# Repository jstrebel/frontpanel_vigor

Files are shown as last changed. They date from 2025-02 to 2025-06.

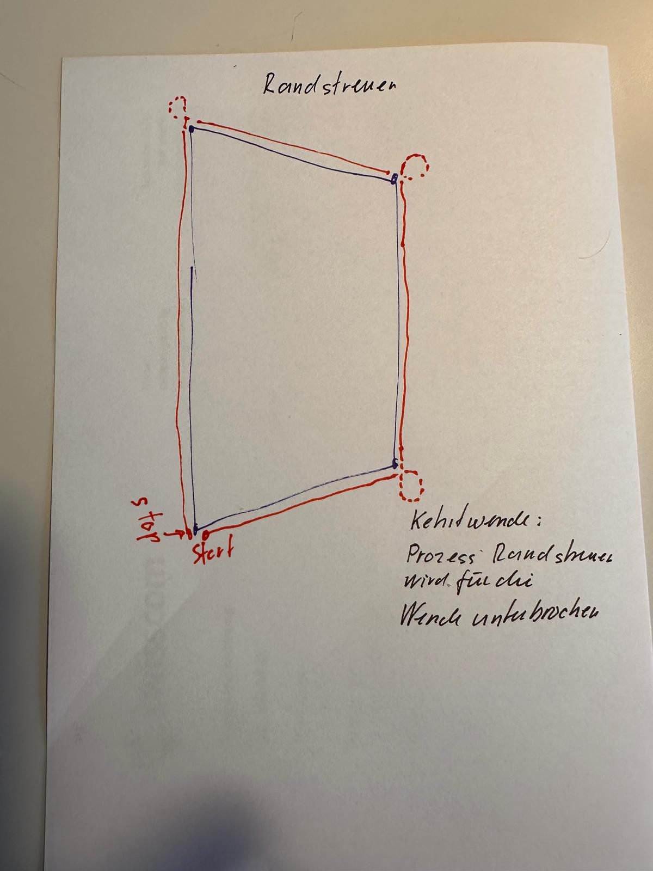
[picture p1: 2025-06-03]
Bedienung/Randstreuen_skizze.jpg

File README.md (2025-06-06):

# vigor frontpanel mit Folientastatur.

Bedienung:  Entwurf der das Bedieninterface der Kotrollerbox erklärt

Schemas:

Testcode:     Beispiel lesen der Tastatur input mit dem Arduino

TFT display:  Für die Anzeigen wird ein gut Dokumentierte Library verwendet.
Doku auf: https://github.com/gavinlyonsrepo/Display_Lib_RPI

Das ist der Code welcher der Entwickler für mich machte.
Dieser Code ist mit dem Raspi 4 getestet.
https://github.com/gavinlyonsrepo/ST7789_TFT_RPI/releases

Gavin hat die Beschreibung upgedatet, Grund war, dass der code den wir verwenden eine andere Library verwendet.
https://github.com/gavinlyonsrepo/ST7789_TFT_RPI

<<<<<<< Updated upstream
<<<<<<< Updated upstream
BEM: werde dieses Repository weiter organisieren und aufräumen 

## Installationen im Raspi

### bcm2835
```
curl -sL http://www.airspayce.com/mikem/bcm2835/bcm2835-1.75.tar.gz | tar xz
./configure
make
sudo make check
sudo make install
```

### redis 
https://fleetstack.io/blog/redis-on-raspberry-pi-setup
```
sudo apt install redis-server -y
```

Falls wenig RAM Memorybegrenzung:
```
sudo nano /etc/redis/redis.conf
maxmemory 100mb maxmemory-policy allkeys-lru
```

Hinzufügen zum Autostart und starten von redis 
```
sudo systemctl  enable  redis-server
sudo systemctl start redis-server
```

Testen:
```
redis-cli
set  testkey  "hello"
get testkey
```

### hiredis
```
sudo apt-get install libhiredis-dev
```
=======
BEM: Werde dieses Repository weiter organisieren und aufräumen
>>>>>>> Stashed changes
=======
BEM: Werde dieses Repository weiter organisieren und aufräumen
>>>>>>> Stashed changes

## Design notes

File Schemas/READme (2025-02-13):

Verkabelung howag: Schemas nach denen Howag die Verkabelung herstellt
Display Anschluss: PCB Verbindungen Display, Folientasten und LED Anzeigen in der Folientastatur
Blockschaltbild: Vigor Bedienung und Regler
Steuerbox: Raspi, und Arduino Display Kontroller
Motor Regler: Steuerung der Linak Linarmotoren. Kommuniziert via CAN Bus mit der Steuerbox

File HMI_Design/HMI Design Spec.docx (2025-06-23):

# HMI Design Spezifikation

# 1 Übersicht

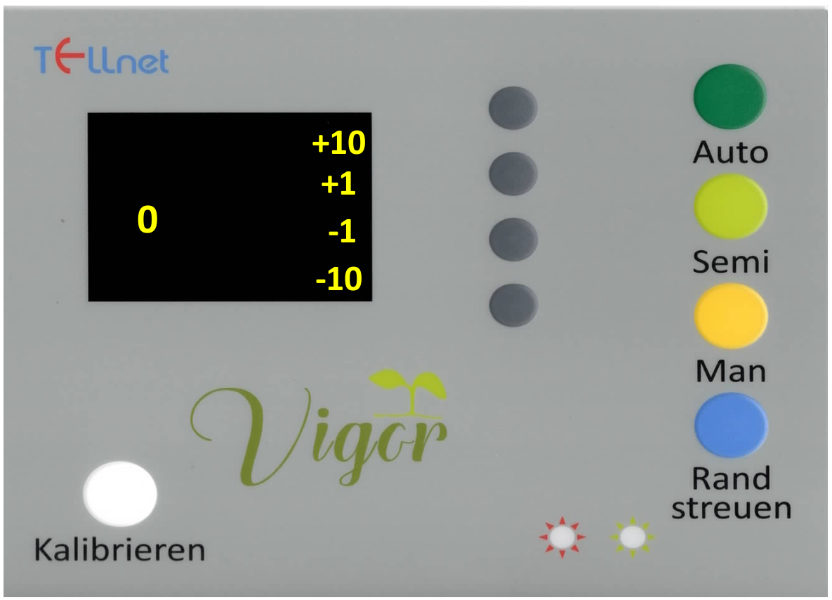
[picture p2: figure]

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
L1 - L7 LEDs

B1 – B5 Knöpfe die mit 3 s debounced werden

B6 – B9 Knöpfe die mit 1 s debounced werden

# 2 Statemachine

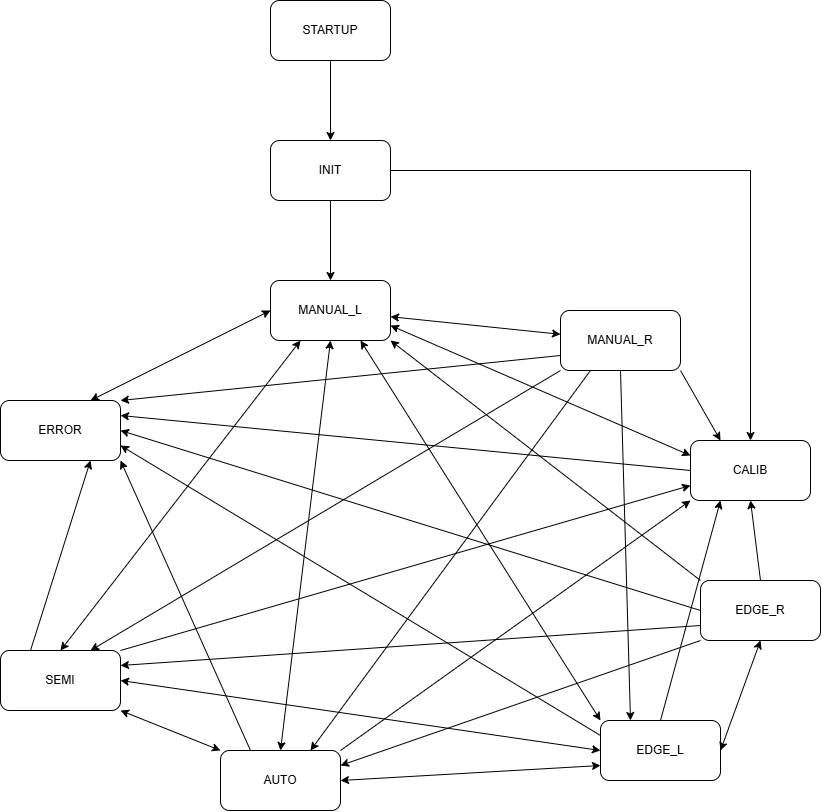
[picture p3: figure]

Alle Verbindungen zum ERROR-State sind im nachfolgenden Kapitel nicht mehr aufgeführt und können durch jeden Fehler zu jedem Zustand hervorgerufen werden.

Der Übergang von STARTUP nach INIT erfolgt nach 10 s.

# 3 UI Konzept

Platzhalter | Bezeichnung | Range | Redis Variable
123 | kalibrierte Position virtueller Anschlag | 0-1023 | hmi_vend_ist
111 | Sollposition virtueller Anschlag | 0-1023 | hmi_vend_soll
11% | Istposition Motor links | 0-100% | hmi_pos_l
22% | Istposition Motor rechts | 0-100% | hmi_pos_r
33% | Sollposition Motor links | 0-100% | hmi_soll_l
44% | Sollposition Motor rechts | 0-100% | hmi_soll_r
Feldname | Name des geladenen Feldes | ?? | hmi_feldname
25 km/h | aktuelle Geschwindigkeit | ?? | hmi_speed
GPS: ok | Status des GPS | ?? | hmi_gps
- | State | - | hmi_state
- | Fehler | 0x01-0x99 | hmi_fehler

Alle Variablen sind vom Datentyp String.

## STARTUP

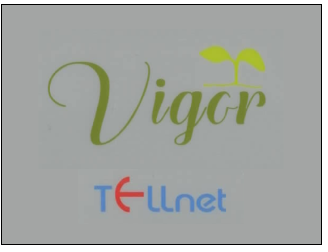
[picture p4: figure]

| Knopf Funktion B1 - B2 - B3 - B4 - B5 - B6 - B7 - B8 - B9 -

## INIT

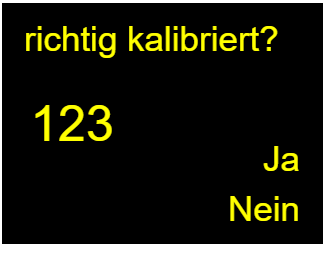
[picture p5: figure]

| Knopf Funktion B1 - B2 - B3 - B4 - B5 - B6 - B7 - B8 - MANUAL_L B9 - CALIB

## CALIB

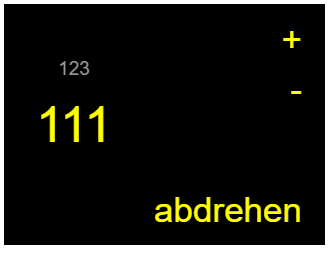
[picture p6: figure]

| Knopf Funktion B1 - AUTO B2 - SEMI B3 - MANUAL_L B4 - EDGE_L B5 vend_prov speichern - MANUAL_L B6 inkrementieren vend_prov B7 dekrementieren vend_prov B8 - B9 Motor links auf vend_prov fahren

## MANUAL_L

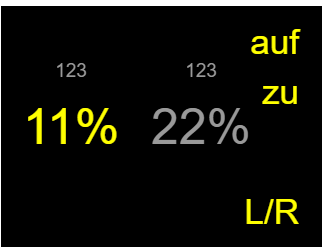
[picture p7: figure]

| Knopf Funktion B1 - AUTO B2 - SEMI B3 - B4 - EDGE_L B5 - CALIB B6 Motor links öffnen B7 Motor links schliessen B8 - B9 - MANUAL_R

## MANUAL_R

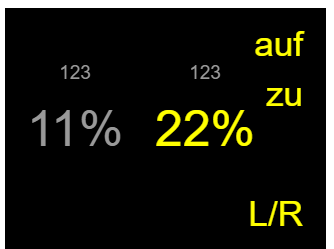
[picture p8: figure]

| Knopf Funktion B1 - AUTO B2 - SEMI B3 - B4 - EDGE_L B5 - CALIB B6 Motor rechts öffnen B7 Motor rechts schliessen B8 - B9 - MANUAL_L

## SEMI

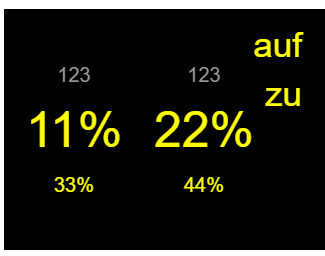
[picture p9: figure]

| Knopf Funktion B1 - AUTO B2 - B3 - MANUAL_L B4 - EDGE_L B5 - CALIB B6 Beide Motoren auf 100% fahren B7 Beide Motoren auf 0% fahren B8 - B9 -

## AUTO

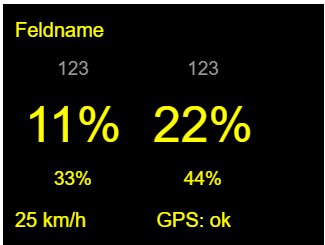
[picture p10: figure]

| Knopf Funktion B1 - B2 - SEMI B3 - MANUAL_L B4 - EDGE_L B5 - CALIB B6 - B7 - B8 - B9 -

## EDGE_L

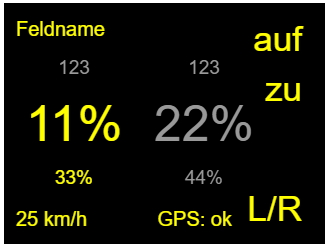
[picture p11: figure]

| Knopf Funktion B1 - AUTO B2 - SEMI B3 - MANUAL_L B4 - B5 - CALIB B6 Motor links auf 100% fahren B7 Motor links auf 0% fahren B8 - B9 - EDGE_R

## EDGE_R

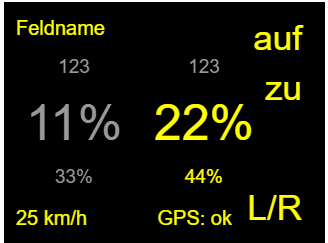
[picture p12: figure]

| Knopf Funktion B1 - AUTO B2 - SEMI B3 - MANUAL_L B4 - B5 - CALIB B6 Motor rechts auf 100% fahren B7 Motor rechts auf 0% fahren B8 - B9 - EDGE_L

## ERROR

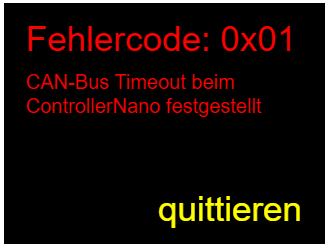
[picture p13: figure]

| Knopf Funktion B1 - B2 - B3 - B4 - B5 - B6 - B7 - B8 - B9 Fehler löschen - MANUAL_L

Fehlercode | Text
0x01 | CAN-Bus Verbindungsunterbruch zum ControllerNano
0x02 | CAN-Bus Verbindungsunterbruch zum Raspberry
0x03 | Motor links einfahren blockiert
0x04 | Motor links ausfahren blockiert
0x05 | Motor rechts einfahren blockiert
0x06 | Motor rechts ausfahren blockiert
0x07 | ??

# 4 Output-Definition

| L1 | L2 | L3 | L4 | L5 | L6 | L7
STARTUP
INIT
CALIB
MANUAL_L
MANUAL_R
SEMI
AUTO
EDGE_L
EDGE_R
ERROR

grün: ON

rot: OFF

blau: BLINK

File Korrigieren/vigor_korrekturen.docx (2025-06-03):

hoi köbi

update zum vigor:

• de widerstand isch de glich gsi wie bim andere multiplexer

• ha jetzt s2 und s1 zemeglötet und jetzt funktionierts

für die nächst Iteration müsst me entweder s2 uf gnd zieh oder am Zero amene freie pin ahenke so dass es nüm Floating irgend es potenzial dra het

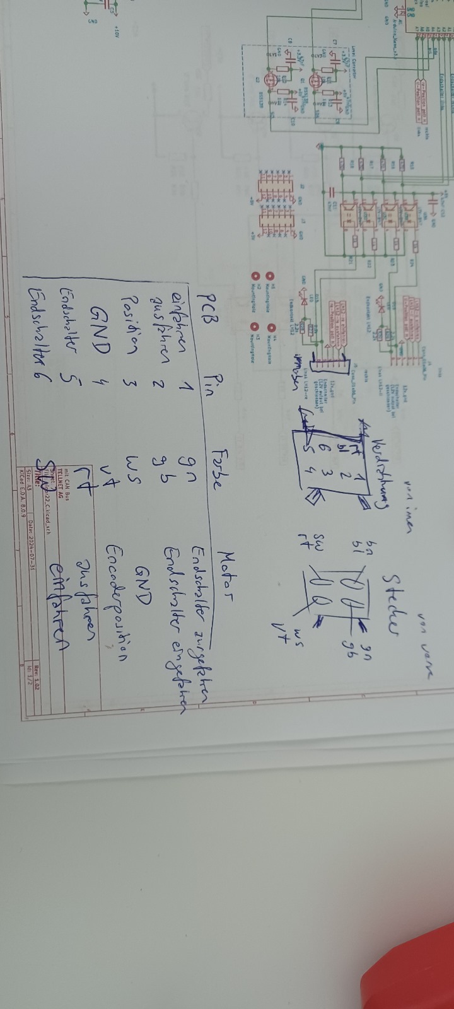
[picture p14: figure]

[13.05.25, 12:42:54] Daniel Jakober: hoi köbi

folgendes Problem:

ich ha ufem raspi d can verbindig wölle teste mitem regler. d verbindig selber het guet funktioniert aber komischerwis hani vom regler immer motorposition 0 übercho was eigentlich gar nit cha si wil de Encoder immer 0.5-4.5v schickt.

denn mol ei Motor abghänkt und wider aghänkt und grad de Arduino gschlisse.

ufgrund vo dem hani denn die neu verkablig dureprüeft und festgstellt dass entweder de motorestecker oder de wissi stecker für ufe print spiegelverchehrt isch. ufem foti gsehsch mini Analyse.

ich probier jetzt mol de Motor manuell z stüre zum luege öb er no funktioniert, wil mit de aktuelle verkablig de Encoder direkt e churze uf gnd gmacht het. falls er no funktioniert luegi öb d platine no lebt, verkable um und nimm e neue Arduino

[13.05.25, 13:38:10] Daniel Jakober: d motore lebe no.

ich nimm ah dass de stecker ufem print bim design oder bim löte verchehrt ume druf cho isch will d howag hets nach ihrem Schema verdrohtet und das passt sowit

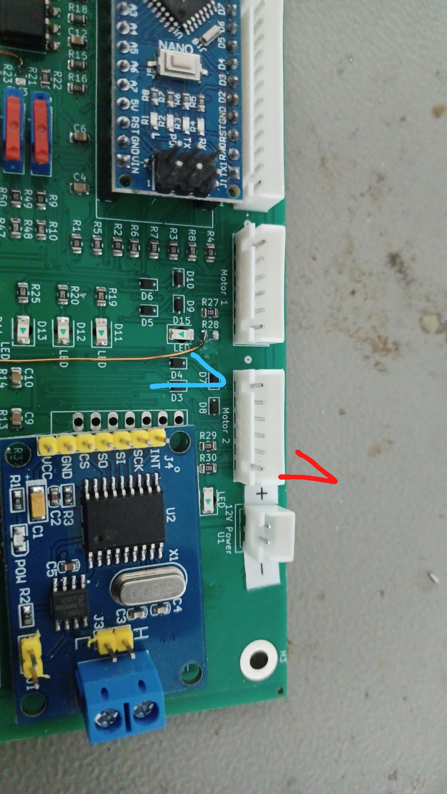
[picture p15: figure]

Rot: stecker pin 1

Blau: platine pin 1

Ich dreih jetz d buchse um denn sötts stimme

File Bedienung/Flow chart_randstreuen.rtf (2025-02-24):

Die Funktion Randstreuen ermöglicht auch eine teilflächenspezifische Düngung, wenn die Feldgrenzen nicht exakt erfasst sind. Dieser Arbeitsschritt steht am Anfang des eigentlichen Düngevorganges. Dabei wird das Feld zu Beginn einmal mit dem Düngerstreuer umfahren. Dabei wird der Dünger nur auf das zu düngende Feld geworfen.
Je nach Strategie oder Düngerstreuer wird das Feld im Uhrzeigersinn (RE) oder Gegen-Uhrzeigersinn (LI) umfahren.

1.Mit dem Traktor zur Anfangsposition fahren.
2.Taste „Man“ 5 Sekunden drücken. → LED „Man“ leuchtet.
3.Taste „Randstreuen“ 5 Sekunden drücken.
1.Anzeige Display Randstreuen
4.Richtung wählen: RE (rechts) oder LI (links).
1.Anzeige Display RE & LI
5.Taste „Randstreuen“ 1 Sekunde drücken.
1.Der Vorgang startet.
2.Sobald der Traktor fährt, öffnet sich der entsprechende Schieber automatisch.
3.LED „Randstreuen“ leuchtet.
6.Ende der Teilstrecke:
1.Traktor kurz anhalten → Schieber schließt automatisch.
2.Taste „Randstreuen“ 1 Sekunde drücken → Unterbrechung zur Wende.
3.LED „Randstreuen“ blinkt.
7.Fortsetzen:
1.Taste „Randstreuen“ erneut 1 Sekunde drücken.
2.LED „Randstreuen“ leuchtet.
3.Sobald der Traktor fährt, öffnet sich der Schieber automatisch.
8.Wiederholen Sie Schritte 5-7, bis das gesamte Feld abgegrenzt ist.
9.Abschluss:
1.Taste „Randstreuen“ 5 Sekunden drücken.

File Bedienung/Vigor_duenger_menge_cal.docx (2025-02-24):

Entwurf: Düngermenge kalibrieren.

Eingabe über Bedienungspanel

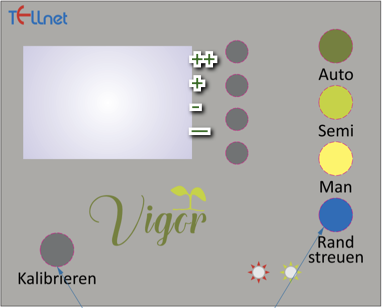
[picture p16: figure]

1) Status setzen Man
2) Button Kalibrieren drücken (5 Sec) (Verriegelung! geht nur wenn Status Man angewählt ist)
3) Kalibriert wird nur mit dem linken Motor. Der rechte Motor (Schieber ist geschlossen)
4) Mit Paneltasten (Funktionstasten neben dem Display) auf grobe Position fahren. (die Position entnimmt der Landwirt einer Tabelle, die vom Düngerstreuer Hersteller geliefert wird)
  a. (wir haben 4 Tasten zur Verfügung. Öffnen/Schliessen, +10, +1, -1, -10)
  b. Anzeige der Position auf dem Display.
    i. 0 -> Linearmotor geschlossen, max. Wert voll ausgefahren.
5) Alternativ: Falls für den gewählten Dünger eine Kalibrierung bereits existiert, wird der Wert mit den Tasten 1-4 eingestellt. Dann gehen Sie direkt zu Punkt 10
6) Abdrehen der Düngemenge (Düngerstreuer wird für eine definierte Zeit eingeschaltet). Die Menge wird danach vom Landwirt mit einer Waage gemessen.
7) Korrigieren (Falls Menge noch nicht OK war)
  a. Wieder wie 3a
  b. Kurzes drücken (0.5 – 1 Sec) von Button Kalibrieren
    i. Motor fährt zuerst etwas Richtung schliessen und danach wieder auf die Position bei der Cal gedrückt wurde. (dies wird gemacht, um das mechanische Spiel zu eliminieren)
8) Erneutes abdrehen (wie punkt 6)
9) If not OK, Wiederholen Step 7
10) IF ok Taste Kalibrieren 5 Sek drücken

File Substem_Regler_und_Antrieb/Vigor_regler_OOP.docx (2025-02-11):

Hier ist die Dokumentation für das angegebene C++-Programm:

## Programmbeschreibung

Dieses C++-Programm steuert ein System, das auf drei Betriebsmodi ausgelegt ist: Semi-Automatik, Automatik und Manuell. Es beinhaltet Fehlerbehandlung, Kommunikationsschnittstellen und LEDs zur Anzeige des Betriebsstatus. Die Hardware wird über I2C und GPIO angesteuert, während verschiedene Zustände und Befehle verarbeitet werden.

## Dateistruktur und Imports

Das Programm verwendet die folgenden benutzerdefinierten Header-Dateien:

- DevOptions.h: Konfigurationseinstellungen.
- PinMap.h: Zuweisung der Hardware-Pins.
- I2C.h: Verwaltung der I2C-Kommunikation.
- Memory.h: Speicherzugriff und Datenpersistenz.
- Logger.h: Protokollierung von Nachrichten.
- LED.h: Steuerung der LEDs.
- CAN.h: (nicht genutzt in diesem Codeabschnitt, möglicherweise für CAN-Kommunikation).
- Controller.h: Steuerung von Motoren.

## Hauptkonstanten und Variablen

### Konstanten

- dt_loop (2 ms): Zeitintervall für die Hauptschleife.

### Globale Variablen

- old_loop_time: Verfolgt die vergangene Zeit zwischen Schleifendurchläufen.
- curr_state: Gibt den aktuellen Betriebsmodus an.
  - 1: Semi-Automatik
  - 2: Automatik
  - 3: Manuell
  - 4: Fehler
- err_shout: Kontrolliert die Fehlerprotokollierung.
- Controller-Objekte: controller_l (links) und controller_r (rechts).
- LED-Objekte: led_red (rot) und led_green (grün).

## Programmfluss

### 1. setup()

Initialisierung der Hardware und der Controller:

1. Initialisierung der Pin-Zuweisung (via PinMap).
2. Initialisierung des Loggers und der I2C-Kommunikation.
3. Erstellung der Controller-Objekte mit ihren zugehörigen Pins und initialen Einstellungen.
4. Initialisierung der LED-Objekte.
5. Protokollierung der Startmeldung.

### 2. loop()

Wird in regelmäßigen Intervallen (dt_loop) ausgeführt und enthält die Hauptlogik:

- I2C-Register-Updates: Synchronisation von Status und Motorpositionen mit den I2C-Registern.
- Moduswechsel: Verarbeitung des aktuellen Modus und Zustandsänderungen basierend auf Eingaben.
- Fehlerbehandlung: Automatische Fehlerkorrektur und Protokollierung.

#### Betriebsmodi

1. Semi-Automatik (State 1):
  - Motorsteuerung basierend auf semiautomatischen Regeln.
  - Aktivierung der grünen LED.
  - Umschaltung in andere Modi basierend auf Schalterstellungen.
2. Automatik (State 2):
  - Motorsteuerung basierend auf Referenzwerten aus dem I2C-Register.
  - Verbindungskontrolle über das Heartbeat-Register.
  - LED-Anzeigen anpassen und Umschaltung in andere Modi.
3. Manuell (State 3):
  - Motorstillstand (Halt).
  - Möglichkeit, virtuelle Endanschläge zu speichern.
  - LED-Anzeigen anpassen und Umschaltung in andere Modi.
4. Fehler (State 4):
  - Motorbewegung zur Fehlerkorrektur (Home).
  - Protokollierung von Fehlern und Aktivierung der roten LED.
  - Fehlerzustand bleibt bestehen, bis er manuell zurückgesetzt wird.

### 3. update_state(short state)

Wechselt den aktuellen Zustand des Systems:

1. Beendet aktuelle Motoraktivitäten.
2. Setzt die I2C-Referenzregister zurück.
3. Protokolliert den Wechsel in den neuen Zustand.

### 4. update_status()

Aktualisiert den Status des Systems und verarbeitet Befehle aus dem I2C-Befehlsregister:

- Speichert neue virtuelle Endanschläge.
- Setzt Fehler zurück.
- Veranlasst einen Übergang aus dem Fehlerzustand.
- Aktualisiert Fehler-Flags und Zustandsbits im Statusregister.

### 5. I2C-Ereignisfunktionen

- receiveEvent(int howMany): Empfängt Daten über I2C.
- requestEvent(): Beantwortet I2C-Anfragen.

## Funktionen der Klassen

1. Controller: Verarbeitet Motorsteuerung (Halt, Semi-Automatik, Automatik, Fehlerkorrektur).
2. LED: Steuert die LEDs (z. B. Blinken, Ein-/Ausschalten).
3. Memory: Speichert und liest die virtuellen Endanschläge.
4. Logger: Protokolliert Ereignisse und Statusänderungen.
5. I2C: Schnittstelle zur Kommunikation und Registerverwaltung.

## Fehlerbehandlung

- Überwacht Watchdog- und Timeout-Fehler.
- Protokolliert spezifische Fehler basierend auf Status-Bits.
- Verhindert wiederholte Fehlermeldungen (err_shout).

## Zusammenfassung

Das Programm ist ein robustes Steuerungssystem, das mehrere Modi unterstützt, eine präzise Motorsteuerung ermöglicht und eine zuverlässige Fehlerbehandlung bietet. Es ist modular aufgebaut, was die Erweiterbarkeit erleichtert.

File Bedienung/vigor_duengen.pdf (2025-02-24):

# Düngen

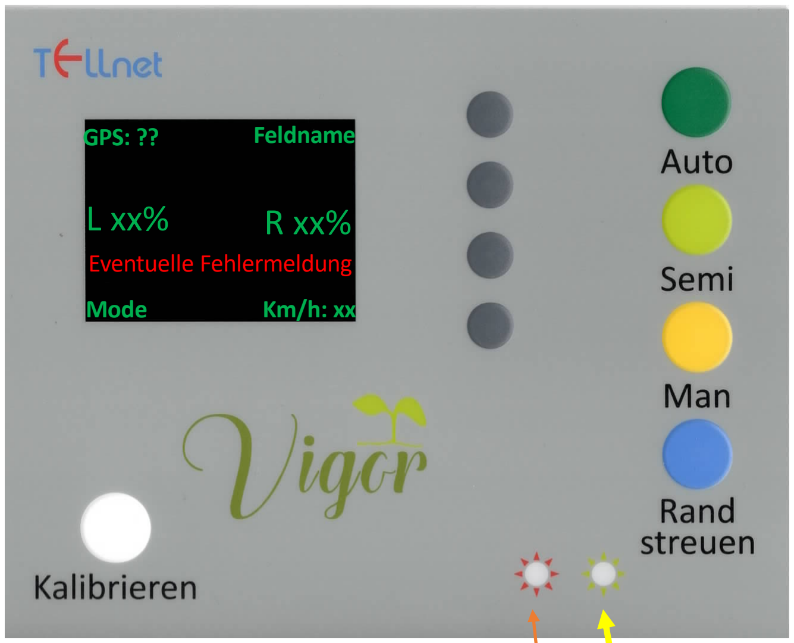
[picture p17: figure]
GPS: ??; Feldname; Mode; Eventuelle Fehlermeldung

### Anzeigen Düngemodus - GPS Status: (locked, not ready) L oder S

- Feldname: Hier wird das Feld angezeigt,

### das in unmittelbarer Nähe ist oder gedüngt

wird.

### - %tuale Schierberöffnung - Betriebsmodus: (Auto, Semi, Man) Kalibrieren, Geschwindigkeit)

## LED ON Alles OK - Kalibrierung ok - Motor Initialisierung ok Bereit zum düngen LED blinkend Bereit zum Düngen, noch kein Düngeplan geladen

## Blinkmuster Müssten noch definiert werden

# Bedienung

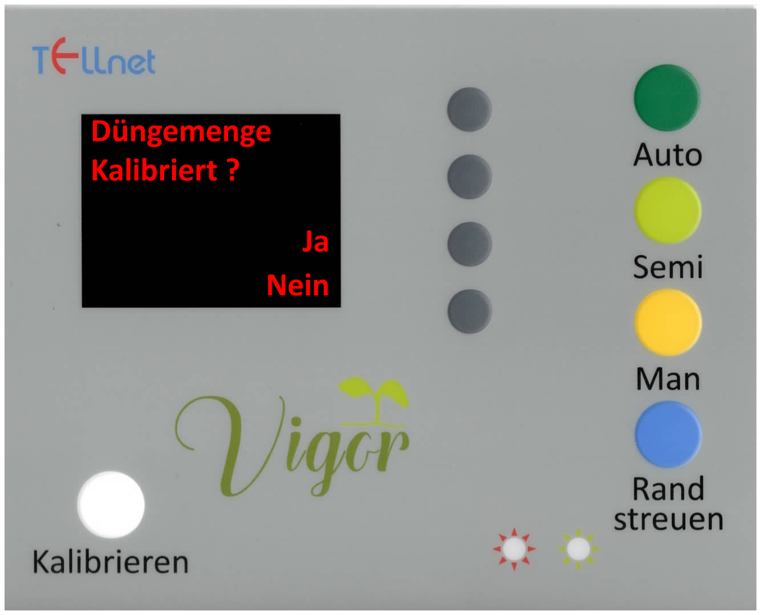
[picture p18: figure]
Düngemenge Kalibriert ?; Nein

Einschalten und Ausgangsposition:
- Schalten Sie den Vigor Düngerstreuer ein.
- Das System startet automatisch im manuellen Modus.
- Die Schieber des Streuers werden initial geschlossen. Kalibrierungsprüfung:
- Auf dem Display erscheint die Frage: "Ist der Düngerstreuer kalibriert?"
- Wählen Sie mit der entsprechenden Taste "Ja" oder "Nein". Kalibrierung (falls erforderlich):
- Wenn "Nein" gewählt wurde:
- Navigieren Sie gemäß den Anweisungen auf dem Display zum Menüpunkt "Düngermenge kalibrieren".
- Führen Sie die Kalibrierung gemäß den detaillierten Anweisungen im Kalibrierungsmenü durch.
Betriebsbereitschaft:
- Wenn "Ja" gewählt wurde oder die Kalibrierung erfolgreich abgeschlossen ist:
- Der Düngerstreuer ist nun betriebsbereit.
- Sie können nun die gewünschten Düngekarten in das System laden.
- Fahren Sie zu den entsprechenden Feldern, um mit dem Düngen zu beginnen.

# Kalibrieren

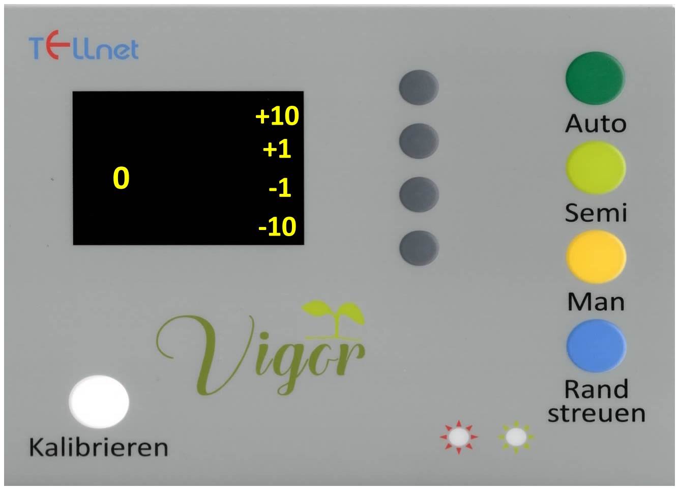
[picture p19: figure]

### 1) Status setzen: Man 2) Button Kalibrieren drücken (5sec) (Verriegelung! geht nur, wenn Status Man angewählt ist) 3) Kalibriert wird nur mit dem linken Motor. Der rechte Motor (Schieber ist geschlossen)

4) Mit Paneltasten (Funktionstasten neben dem Display) auf grobe Position fahren.
(die Position entnimmt der Landwirt einer Tabelle, die vom Düngerstreuer Hersteller geliefert wird)

### a. (wir haben 4 Tasten zur Verfügung. +10, +1, -1, -10)

b. Anzeige der Position auf dem Display.
i. 0 -Schieber geschlossen, max. Wert voll ausgefahren.

5) Alternativ: Falls für den gewählten Dünger eine Kalibrierung bereits existiert, wird der Wert mit den Tasten 1-4 eingestellt. Dann gehen Sie direkt zu Punkt 10 6) Abdrehen der Düngemenge (Düngerstreuer wird für eine definierte Zeit eingeschaltet). Die Menge wird danach vom Landwirt mit einer Waage

gemessen.

7) Korrigieren (Falls Menge noch nicht OK war) a. Wie 3a b. Kurzes drücken (0.5 – 1sec) von Button Kalibrieren i. Motor fährt zuerst etwas Richtung schliessen und danach wieder auf die Position bei der Cal gedrückt wurde. (dies wird gemacht, um das mechanische Spiel zu eliminieren) 8) Erneutes abdrehen (wie Punkt 6) 9) IF not OK, Wiederholen (wie Punt 7) 10) IF ok Taste Kalibrieren 5 Sek drücken

# Randstreuen

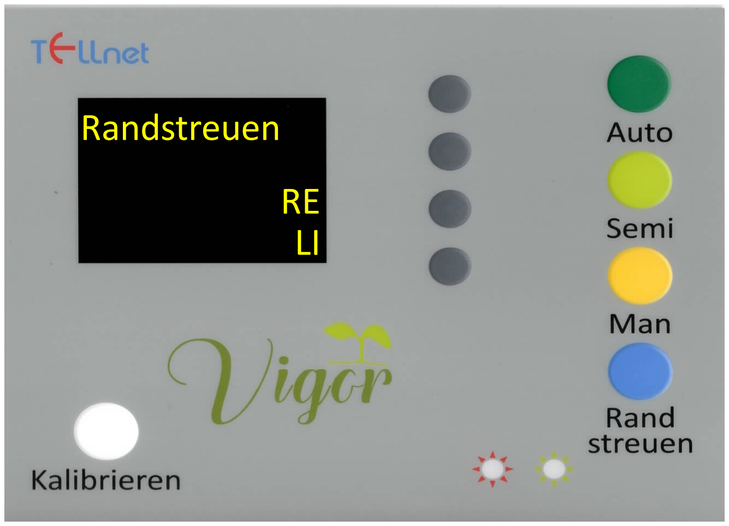
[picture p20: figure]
Randstreuen

Die Funktion Randstreuen ermöglicht auch eine teilflächenspezifische Düngung, wenn die Feldgrenzen nicht exakt erfasst sind. Dieser Arbeitsschritt steht am Anfang des eigentlichen Düngevorganges. Dabei wird das Feld zu Beginn einmal mit dem Düngerstreuer umfahren. Dabei wird der Dünger nur auf das zu düngende Feld geworfen.
Je nach Strategie oder Düngerstreuer wird das Feld im Uhrzeigersinn (RE) oder Gegen-Uhrzeigersinn (LI) umfahren.

1.Mit dem Traktor zur Anfangsposition fahren.
2.Taste „Man“ 5 Sekunden drücken. → LED „Man“ leuchtet. 3.Taste „Randstreuen“ 5 Sekunden drücken.
1.Anzeige Display Randstreuen
4.Richtung wählen: RE (rechts) oder LI (links).
1.Anzeige Display RE & LI
5.Taste „Randstreuen“ 1 Sekunde drücken.
1. Der Vorgang startet.
2. Sobald der Traktor fährt, öffnet sich der entsprechende Schieber automatisch.
3. LED „Randstreuen“ leuchtet.
6.Ende der Teilstrecke:
1. Traktor kurz anhalten → Schieber schließt automatisch.
2. Taste „Randstreuen“ 1 Sekunde drücken → Unterbrechung zur Wende.
3. LED „Randstreuen“ blinkt.
7.Fortsetzen:
1. Taste „Randstreuen“ erneut 1 Sekunde drücken.
2. LED „Randstreuen“ leuchtet.
3. Sobald der Traktor fährt, öffnet sich der Schieber automatisch. 8.Wiederholen Sie Schritte 5-7, bis das gesamte Feld abgegrenzt ist. 9.Abschluss:
1. Taste „Randstreuen“ 5 Sekunden drücken.

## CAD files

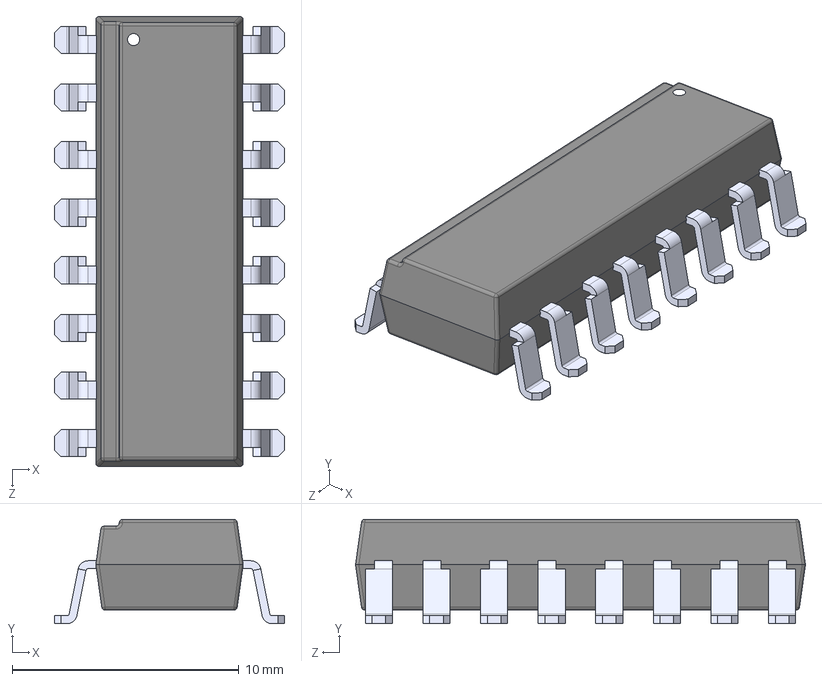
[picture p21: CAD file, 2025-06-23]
KiCAD/vigor22_C/LTV-847S/LTV-847S.step
10.2 x 4.60 x 19.8 mm

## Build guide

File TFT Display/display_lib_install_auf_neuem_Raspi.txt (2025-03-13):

pi@vigor:~ $ curl -sL https://github.com/gavinlyonsrepo/ST7789_TFT_RPI/archive/1.0.2.tar.gz | tar xz

pi@vigor:~ $ ls
Display_Lib_RPI-2.2.0  lg  lg.zip  ST7789_TFT_RPI-1.0.2
pi@vigor:~ $ cd ST7789_TFT_RPI-1.0.2/

********************************

/Display_Lib_RPI-2.2.0
Installieren 

in home von pi
pi@vigor:~ $ ls -l
total 2684
drwxr-xr-x 8 pi pi    4096 Mar 12 09:19 Display_Lib_RPI-2.2.0
drwxr-xr-x 7 pi pi    4096 Mar 12 08:21 lg
-rw-r--r-- 1 pi pi 2739152 May  3  2023 lg.zip

wget http://abyz.me.uk/lg/lg.zip
unzip lg.zip
cd lg
make
sudo make install

macht Fehler
pi@vigor:~/lg $ sudo make install
install -m 0644 lgpio.h                  /usr/local/include
install -m 0644 rgpio.h                  /usr/local/include
install -m 0755 liblgpio.so.1 /usr/local/lib
install -m 0755 librgpio.so.1 /usr/local/lib
install -m 0755 rgpiod                   /usr/local/bin
install -m 0755 rgs                      /usr/local/bin
install -m 0644 rgpiod.1                 /usr/local/man/man1
install -m 0644 rgs.1                    /usr/local/man/man1
install -m 0644 lgpio.3                  /usr/local/man/man3
install -m 0644 rgpio.3                  /usr/local/man/man3
ldconfig
/usr/bin/python3
Traceback (most recent call last):
  File "/home/pi/lg/PY_RGPIO/setup.py", line 3, in <module>
    from setuptools import setup
ModuleNotFoundError: No module named 'setuptools'
*** install of Python3 rgpio.py failed ***
/usr/bin/python3

sudo apt-get install python3-pip

danach	 gehts

cd Display_Lib_RPI-2.2.0
make
sudo make install

cd examples
# Edit the makefile in examples folder by picking the "SRC" file path you want to run

/Display_Lib_RPI-2.2.0/examples $ make help
Makefile:140: *** SRC example file path is not set, pick a SRC path in Section A, exiting nothing done.  Stop.

# =============== ST7789 TFT LCD SPI =============

SRC=st7789/Hello_world

make
make run

 make run
Bin/test.out
TFT Start Test 101 HWSPI
ST7789 library version : 220
Lgpio library version :131584
Hello World
Error: spiWriteDataBuffer: Failure to Write SPI :(spi xfer/read/write failed)
The problem maybe: The spidev buf size setting must be set at 65536 bytes or higher.
See readme, note section, of relevant display at https://github.com/gavinlyonsrepo/Display_Lib_RPI for more details
spidev buf defines the number of bytes that the SPI driver will use as a buffer for data transfers.
Error: spiWriteDataBuffer: Failure to Write SPI :(spi xfer/read/write failed)
The problem maybe: The spidev buf size setting must be set at 65536 bytes or higher.
See readme, note section, of relevant display at https://github.com/gavinlyonsrepo/Display_Lib_RPI for more details
spidev buf defines the number of bytes that the SPI driver will use as a buffer for data transfers.
TFT End

Lösung:

If it is lower than 65536 you can change it by adding this to the start of line in file /boot/firmware/cmdline.txt. Make sure everything is on one line and there is space ' ' between this parameter and next one. Then reboot machine. Verify again by running last cat command above

spidev.bufsiz=65536

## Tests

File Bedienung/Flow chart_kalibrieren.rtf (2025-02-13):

Erstelle Flow Chart mit Gemini:
Funktion kalibrieren:

Funktion F0:
If Cal Button pressed < 1sec
if no valid Value, display: Not Calibrated
display value result.

Funktion F1:
LED cal OFF
Press Cal Button for 5 sec
Blink LED cal
Close Schieber

Funktion F2:
betätige Funktionstasten (+10 / +1/ -1/ -10)
Move Schieber to Position selected by Funktionstasten
Display Position
Motor Position OK ?
Press Cal Button for 1sec

Funktion F3: (Funktion to overcome mechanical hysteresis.
Move Schieber -10%
Move Schieber back to Position when Button cal was pressen.

Funktion F4: External Funktion by User: Check result
IF result not OK go F2
IF result OK
Display Text: Press Cal for 5sec
LED Cal ON

Antwort Gemini:

Explanation:
1 Start: The process begins.
2 Function F0:
◦ Check Cal Button: If the button is pressed for less than 1 second:
▪ Check Valid Value: If a valid value is present, display it.
▪ No Valid Value: If no valid value is present, display "Not Calibrated."
3 Function F1:
◦ LED Cal OFF: Turn off the calibration LED.
◦ Press Cal Button: Wait for the button to be pressed for 5 seconds.
◦ Blink LED Cal: Blink the calibration LED.
◦ Close Schieber: Close the slider.
4 Function F2:
◦ Press Function Buttons: Press the desired function button (+10, +1, -1, -10).
◦ Move Schieber: Move the slider to the position selected by the function buttons.
◦ Display Position: Display the current position.
◦ Check Motor Position: Verify if the motor is in the correct position.
▪ Yes: Proceed to Function F3.
▪ No: Go back to Function F2.
5 Function F3:
◦ Move Schieber -10%: Move the slider 10% backward.
◦ Move Schieber Back: Move the slider back to the position when the calibration button was pressed.
6 Function F4:
◦ External Check: Perform an external check of the result.
▪ Result Not OK: Go back to Function F2.
▪ Result OK: Display "Press Cal for 5sec" and turn on the calibration LED.
7 End: The process ends.

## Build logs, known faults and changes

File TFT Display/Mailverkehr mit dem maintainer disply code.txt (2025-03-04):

MAIL Verkehr mit dem Maintainer des Display Codes:
(chronlogie: Neueste am Anfang)

Hi Gavin,
I intend to use the ST7789_TFT_RPI lib. The lib you did for me.
Is there a possibility to merge this into 2.0. Or should I stay with 1.3?
Regards
Jakob

Am 23.12.2024 um 20:04 schrieb Gavin Lyons <glyons66@hotmail.com>:

Hi 

You are using Display_Lib_RPI not ST7789_TFT_RPI
ST7789_TFT_RPI is  the library I wrote for you.

The problem is:  that I upgraded 'Display_Lib_Rpi' from version 1.3.0 to Version 2.0.0. Last month.
So it will work on all Linux based Single board computers Including  Raspberry pi 5.  
'Display_Lib_Rpi'  version 2.0.0 may require a change to the 'spidev.bufsiz' setting  as specified in the st7789 readme.

Do you want to use Display_lib_RPI OR St7789_TFT_RPI ?
St7789_TFT_RPi is unchanged since last contact and should work fine.

Regards 
Am 23.11.2024 um 14:57 schrieb Gavin Lyons <glyons66@hotmail.com>:

Hi 

I have created a new version: 1.0.2 , which has support for hardware SPI-1 interface.
There are 3 hello world examples (one for SPI-0 , SPI-1 and software SPI)
The only difference is in setup*() function.
 The difference between SPI-0 and SPI-1 is the number of parameters for TFTInitSPI() function.
For SPI-1 there is no choice for CE pin.
I have noticed the speed of SPI-1 is ~50% of SPI-0, I don't know reason why , its not my library, its the bcm2835 library or
Raspberry pi configuration.
Pins used are in README table. 
I never used the SPI-1 before on any project.
Regards
From: Jakob Strebel <jkstrebel@gmail.com>
Sent: Friday 22 November 2024 18:22
To: Gavin Lyons <glyons66@hotmail.com>
Subject: Re: Display Lib st7789 change to Landscape?

Good evening Gavin,

Thank you for the response. Because i am only displaying Text, I guess Software SPI could do the job, right?
The Library as it is has NO option to use  SPI1 
It needs to be changed to use 'bcm2835_aux_spi_*'  functions instead of the  'bcm2835_spi_*'  from bcm2835 dependency library.
I have never used  'bcm2835_aux_spi_*' before but assuming it works it should be an easy job. 
The library does support  software SPI , but this is 20 times slower than 8MhZ Hardware SPI, the advantage of software SPI is you can 
Pick any GPIO you want. 
I can add an option to use SPI1 OR show you how to do software SPI(its shown in hello world example , function = SetupSWSPI()) 

This would be very helpful. 
Regards Jakob

regards
   

From: Jakob Strebel <jkstrebel@gmail.com>
Sent: Thursday 21 November 2024 16:49
To: Gavin Lyons <glyons66@hotmail.com>
Subject: Re: Display Lib st7789 change to Landscape?
 
Gavin,
I hope you got the money. With Paypal the conversion from Swiss Francs, went to US$ and then to EU. This ist the reason for the odd value.

As I confimed yesterday, all works. Thank you.

Right now I am struggling because I need to move the display from the SPI 0 channel to SPI 1.
I could you give me please give me a hint?
Below the Actual pin Config which works. 
Where do I make the all the changes to use SPI 1?

Thank you Jakob

<PastedGraphic-1.png>

Am 20.11.2024 um 17:15 schrieb Gavin Lyons <glyons66@hotmail.com>:

Hi 

I have made a new library at https://github.com/gavinlyonsrepo/ST7789_TFT_RPI
You can test it and see how it works.
I think it will work for 240x320 but i am not certain.

Regards

From: Jakob Strebel <jkstrebel@gmail.com>
Sent: Tuesday 19 November 2024 16:37
To: Gavin Lyons <glyons66@hotmail.com>
Subject: Re: Display Lib st7789 change to Landscape?
 
Hi Gavin,
thank you for the quick response.

So you want a ST7789 Library for Raspberry pi 3 or 4 written in C++, 240x320 Landscape mode.
Yes

Note ::
I have a 240X280 display but the same code should work for 240x320.

Lets give a try with this version. I guess to change it to 240x320 should not be a ig issue.

The 'Display_Lib_RPI' library  does not work at present  with Raspberry pi 5 as the bcm2835 Library dependency its built on is not updated to work  on Raspberry pi 5.

I am aware of this. I am using RP4 ad CM4 with bookworm. Never seen any problem between the two platforms.
Regards Jakob

regards
 
From: Jakob Strebel <jkstrebel@gmail.com>
Sent: Tuesday 19 November 2024 09:30
To: Gavin Lyons <glyons66@hotmail.com>
Subject: Re: Display Lib st7789 change to Landscape?
 
Gavin,
thank you for the response. The positive result lead me to ask you for some work.  I am able to pay a small amount for it.

I am planning to build a small series of devices that will help farmers to reduce the need for fertilizer in order to conserve drinking water. Our aim is to provide around 20-30 farmers with a low-cost device next spring.
We use a TFT display to show the operating status. 
240x320 in landscape mode.
I have discovered your Display_Lib_RPI library.
could you please adapt this library for the ST7789v to:
240x320 Landscape mode. Would this be possible for 100€
Our project is also open source https://github.com/jaluebbe/vigor22

Regards Jakob

Am 17.11.2024 um 23:16 schrieb Gavin Lyons <glyons66@hotmail.com>:

Hi 

You can use command  TFTsetRotation(); to rotate the display.
https://gavinlyonsrepo.github.io/misc/software_docs/Display_Lib_RPI/classST7789__TFT.html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

See test 502 in example file Text_Graphics_Functions/main.cpp 
you have to edit the examples/color16_displays/Makefile To SRC=st7789/Text_Graphics_Functions to run this test file. As per main README test section.

regards.

From: Jakob Strebel <jkstrebel@gmail.com>
Sent: Sunday 17 November 2024 13:39
To: glyons66@hotmail.com <glyons66@hotmail.com>
Subject: Display Lib st7789 change to Landscape?
 
Gavin, great to see what you have done. Thank you for the good description. It helped me to make it run for a st7788 to display Text.

I was searching in the code to find any hints how to change the text display from portrait to landscape mode.
Could you please give me hints wherei can do this?

Regards Jakob

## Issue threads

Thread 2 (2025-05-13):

Adresspin Ti2-S2 fehlt

danielfhnw, 2025-05-13:
Beim Multiplexer U6 für den K9 fehlt der Anschluss am S2.

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

Könnte entweder direkt auf GND gezogen , aber dadurch verlieren wir 4 Kanäle oder am Raspi Zero an einem freien Pin angehängt werden.

danielfhnw, 2025-05-13:
Aktueller Hotfix: S1 und S2 zusammengelötet.

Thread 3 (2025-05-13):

Spiegelverkehrte Stecker

danielfhnw, 2025-05-13:
Der Motorenstecker und die Verkabelung von Howag passen nicht mit der Pinbelegung auf dem Schema überein. Entweder ist der Motorenstecker oder der weisse Stecker für auf den Print spiegelverkehrt verkabelt.

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

danielfhnw, 2025-05-13:
Hotfix: beide PCB-Buchsen gedreht.
Anhand des Footprints sind sie wahrscheinlich 180° verdreht im KiCad

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

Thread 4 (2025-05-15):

FPC spiegelverkehrt

danielfhnw, 2025-05-15:
Der SMD-Flachbandconnector stimmt in der angedachten Ausrichtung nicht mit der Nummerierung des Kabels überein.

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

danielfhnw, 2025-05-15:
Hotfix: Kabel um 180° gedreht damit die Pins übereinstimmen. Kann aber auf Dauer nicht funktionieren, da das Kabel stark verbogen ist.

danielfhnw, 2025-05-15:
Update: Kabel kaputt

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

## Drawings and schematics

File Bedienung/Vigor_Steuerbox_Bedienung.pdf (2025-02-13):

# Vigor Blockschaltbild

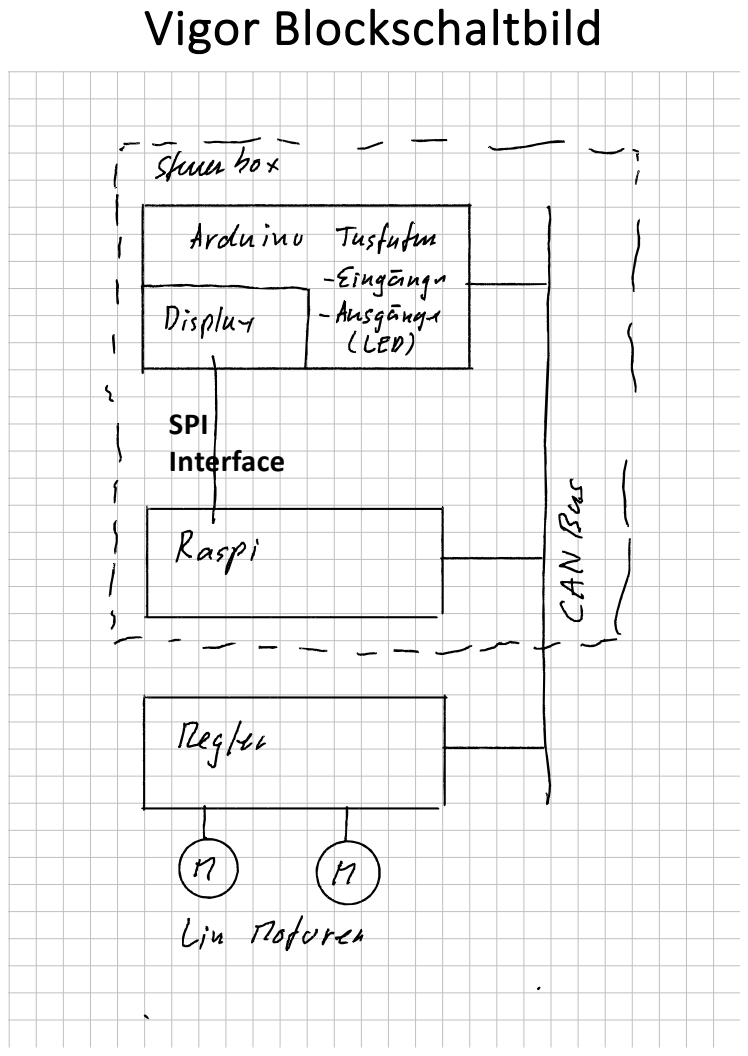
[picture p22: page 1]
SPI Interface

## Anzeige: Betriebsmodus (düngen)

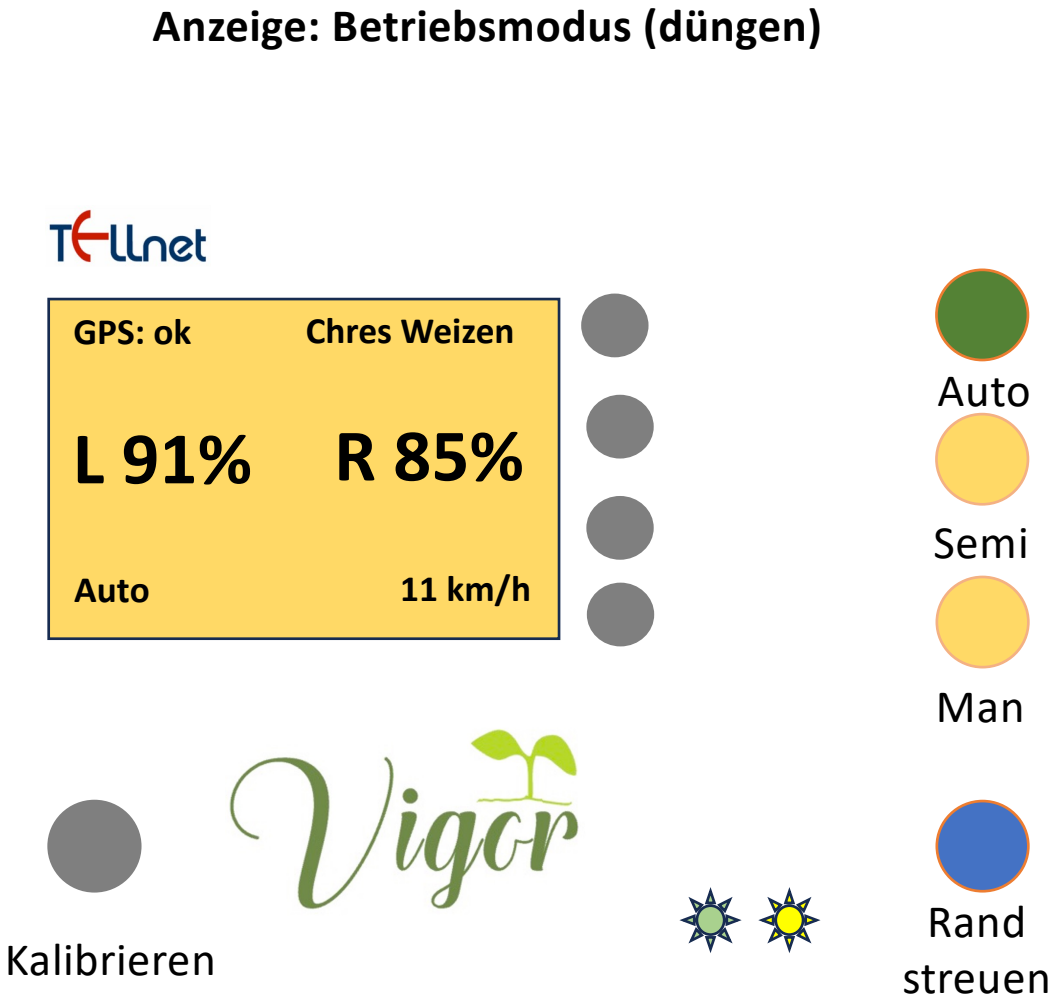
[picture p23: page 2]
Rand streuen Kalibrieren; Man; Semi; Auto; GPS: ok; Chres Weizen

## Erklärungen: Anzeigen

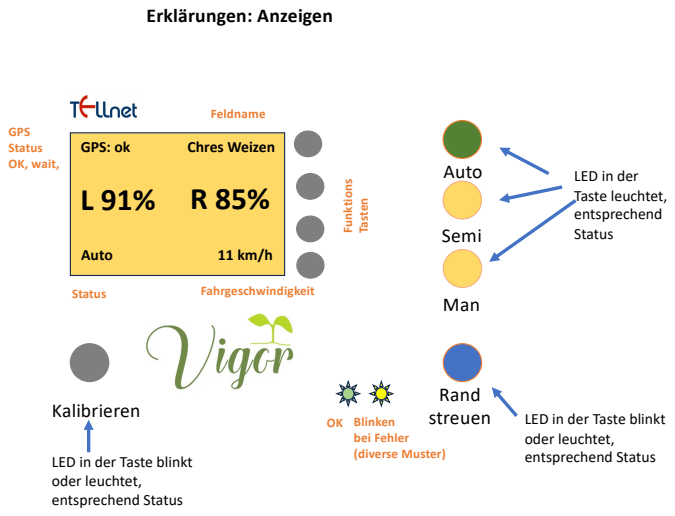
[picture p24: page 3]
Rand streuen Kalibrieren; Man; Semi; Auto; GPS: ok; Chres Weizen; Feldname; Funktions Tasten; Fahrgeschwindigkeit Status; OK Blinken bei Fehler (diverse Muster); GPS Status OK, wait,

LED in der
Taste leuchtet,
entsprechend
Status

LED in der Taste blinkt
oder leuchtet,
entsprechend Status

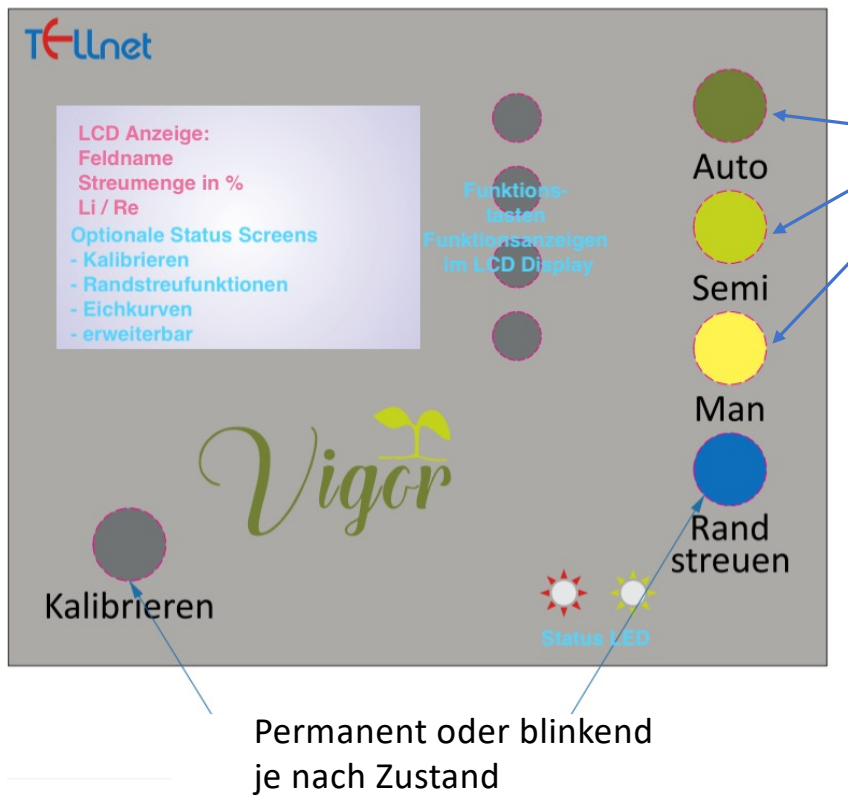
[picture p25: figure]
Permanent oder blinkend je nach Zustand

In den Tasten
ist eine LED die
permanent leuchtet

## Erklärungen zu LCD Anzeige

# Kalibrieren

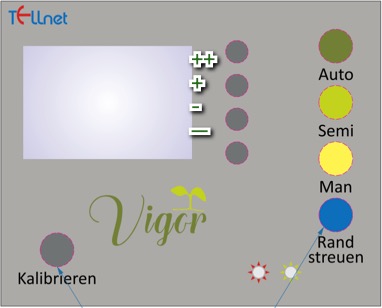
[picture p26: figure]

1) Status setzen: Man
2) Button Kalibrieren drücken (5sec) (Verriegelung! geht nur, wenn Status Man angewählt ist)
3) Mit Paneltasten (Funktionstasten neben dem Display) auf grobe Position fahren. (die Position entnimmt der Landwirt einer Tabelle)
a. (wir haben 4 Tasten zur Verfügung. Öffnen/Schliessen, grosse Schritte kleine Schritte)
b. Anzeige der Position auf dem Display.
i. 0 -> voll Button geschlossen, max. Wert voll ausgefahren.
4) Abdrehen der Menge (Düngerstreuer wird für eine definierte Zeit betätigt. Die Menge wird danach vom Landwirt mit einer Waage gemessen.
5) Korrigieren (Falls Menge noch nicht OK war
a. Wie 3a
b. Kurzes drücken (0.5 - 1sec) von Button Kalibrieren
i. Motor fährt zuerst etwas Richtung schliessen und danach wieder auf die Position bei der Cal gedrückt wurde. (dies wird gemacht, um das mechanische Spiel zu eliminieren)
6) Erneutes abdrehen (wie Punkt 4)
7) IF not OK, Wiederholen Step 5
8) IF ok Taste Kalibrieren 5 Sek drücken

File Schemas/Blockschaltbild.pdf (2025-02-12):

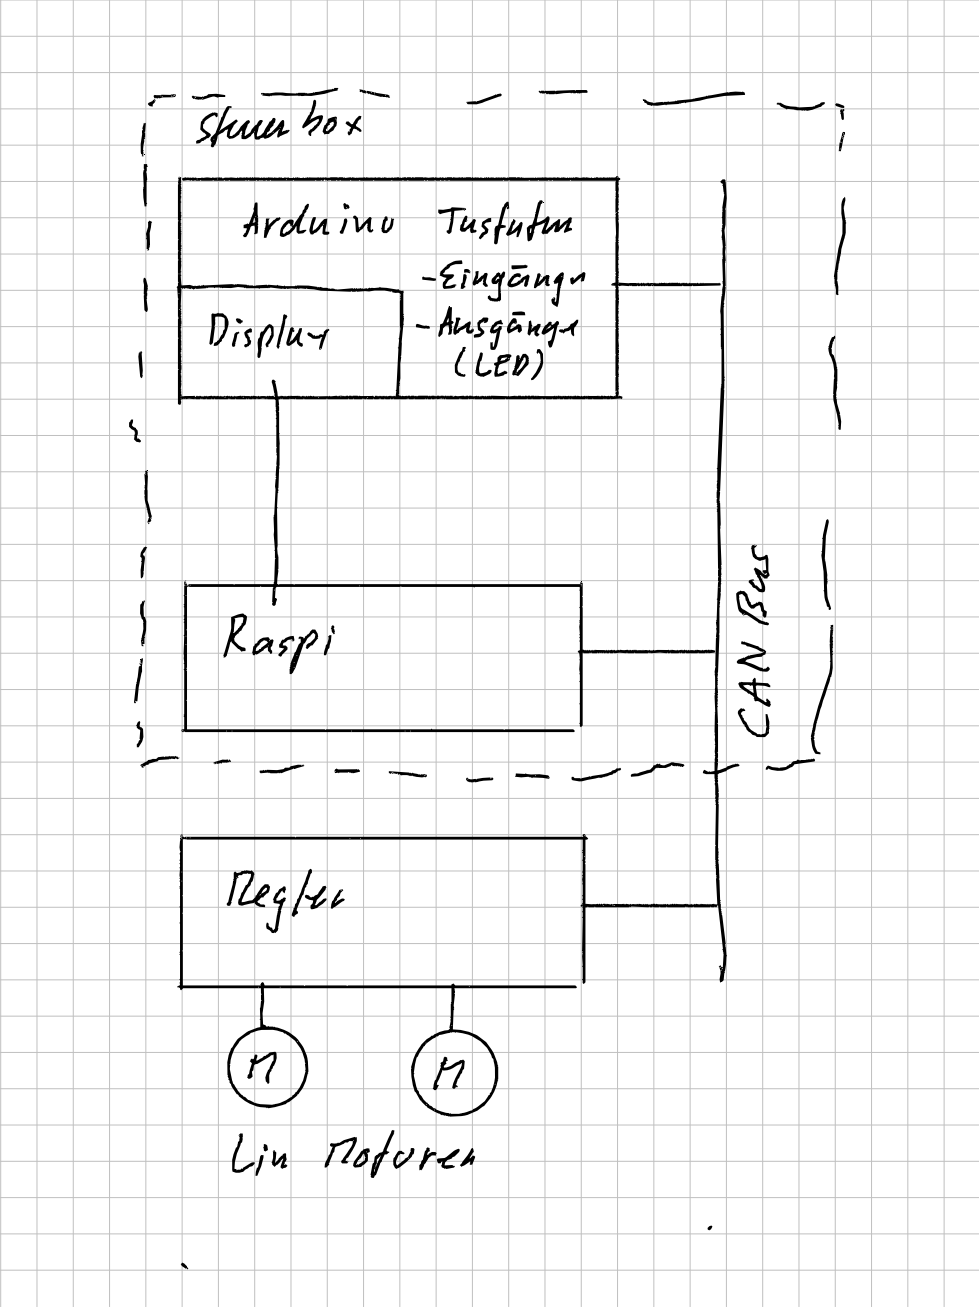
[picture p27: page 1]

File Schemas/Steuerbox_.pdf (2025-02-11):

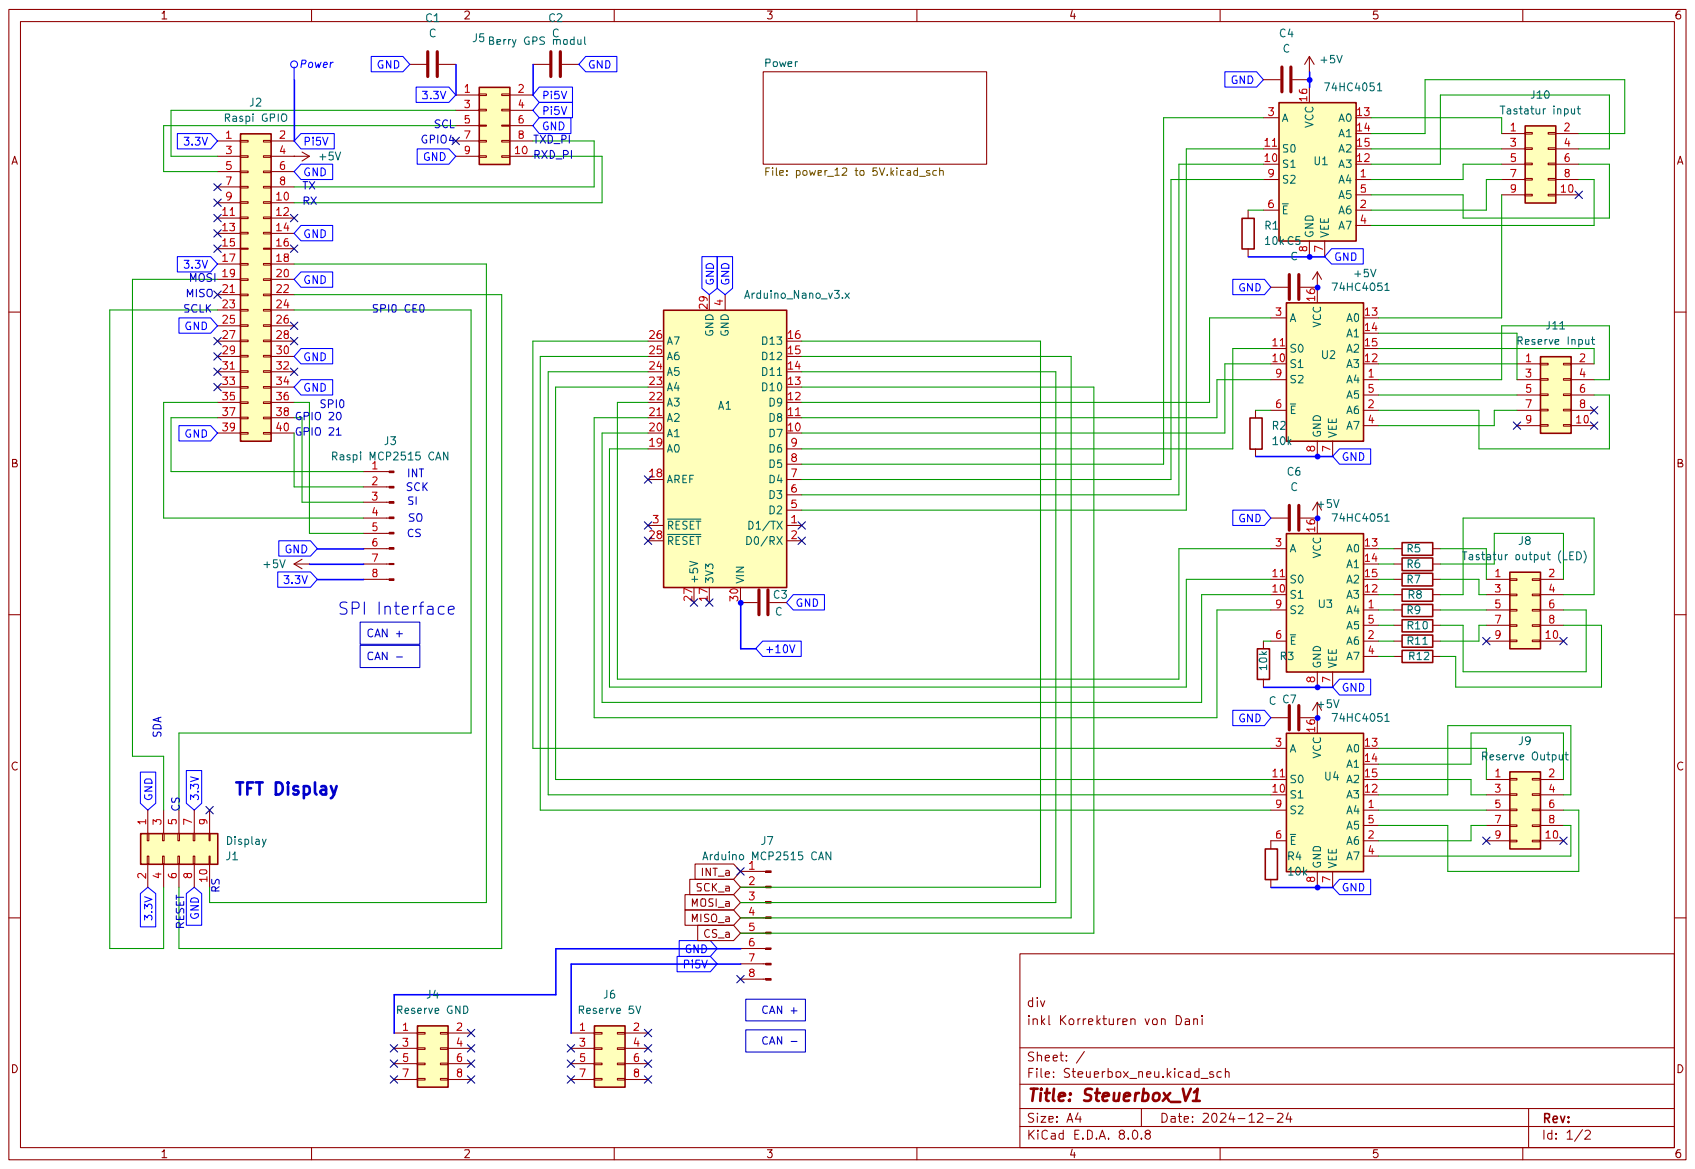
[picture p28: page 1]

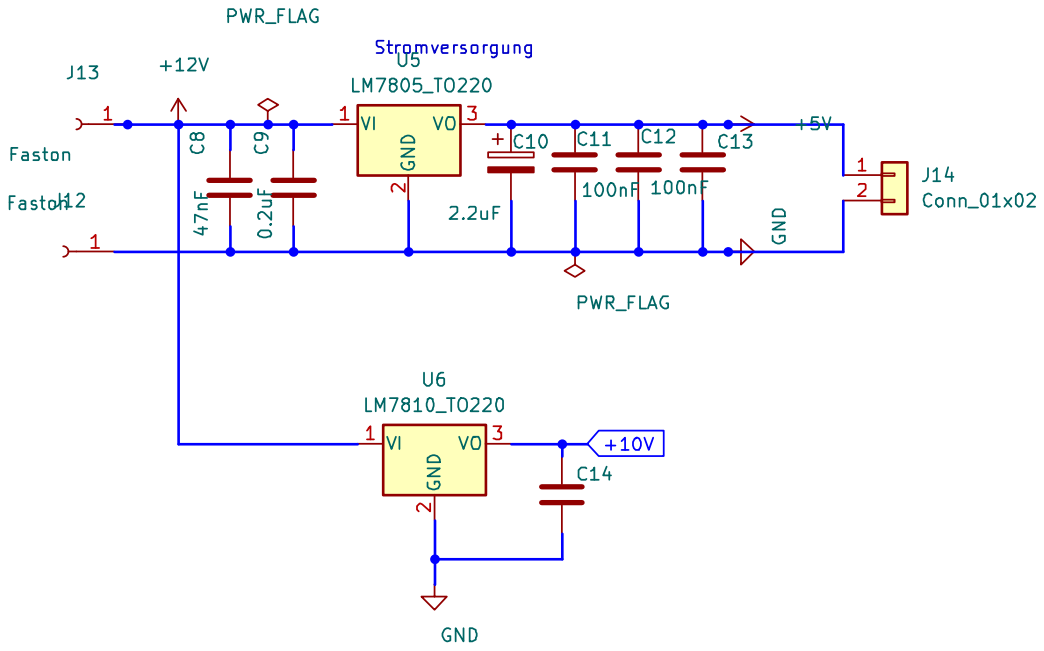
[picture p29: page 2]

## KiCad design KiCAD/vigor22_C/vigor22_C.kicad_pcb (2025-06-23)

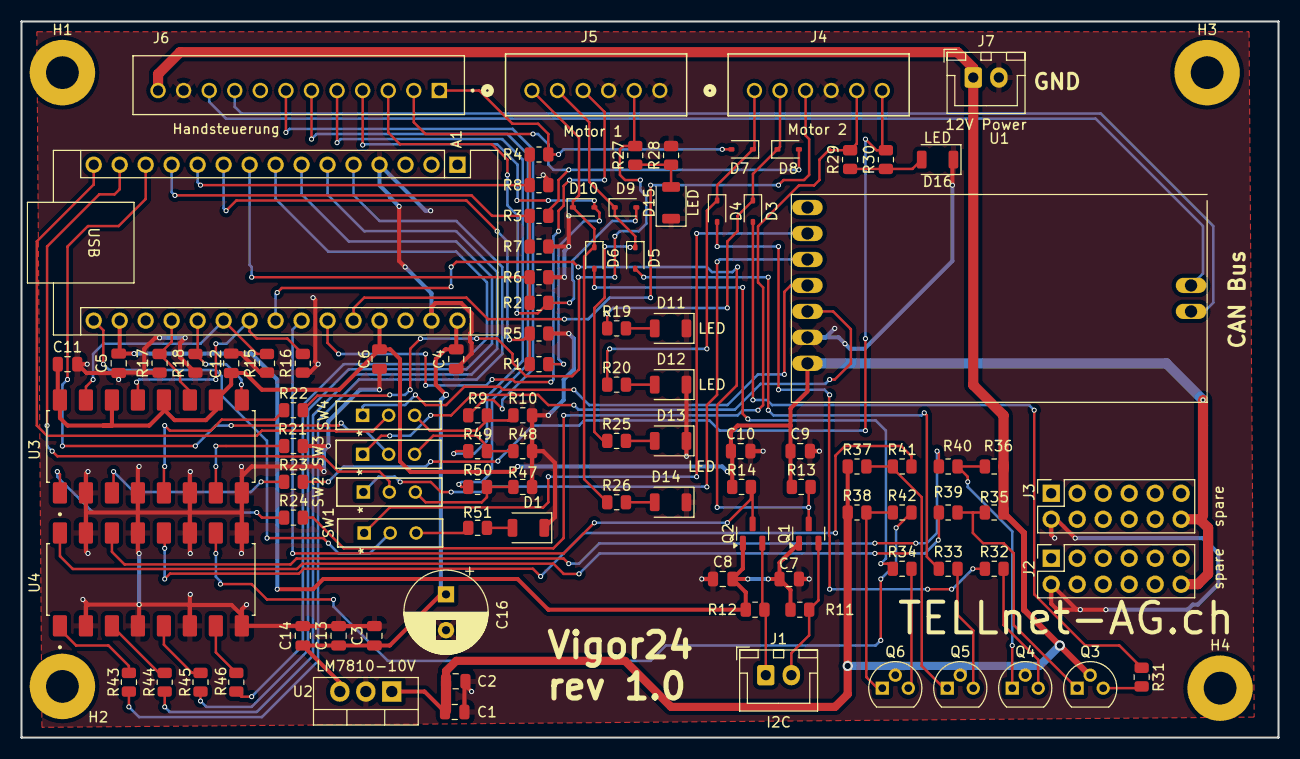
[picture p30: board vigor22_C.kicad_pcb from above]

Board: 2 copper layers, 122.9 x 70.0 mm, 107 parts (0 on the bottom side), 82 nets.

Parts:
A1: Arduino_Nano_v3.x; Arduino_Nano
C1, C2, C3, C4, C5, C6, C7, C8, C9, C10, C11, C12, C13, C14: 47nF; C_0805_2012Metric
C16: 2.2uF; CP_Radial_D8.0mm_P3.50mm
D1, D11, D12, D13, D14, D15, D16: LED; LED_1206_3216Metric_ReverseMount_Hole1.8x2.4mm
D3, D4, D5, D6, D7, D8, D9, D10: D; D_SOD-323
H1, H2, H3, H4: MountingHole; MountingHole_3.2mm_M3_Pad
J1: I2C; JST_XH_B2B-XH-A_1x02_P2.50mm_Vertical
J2, J3: spare; PinSocket_2x06_P2.54mm_Vertical
J4: Motor 2; CONN_B6B-XH-JST
J5: Motor 1; CONN_B6B-XH-JST
J6: Handsteuerung; CONN_B12B-XH-JST
J7: 12V Power; JST_XH_B2B-XH-A_1x02_P2.50mm_Vertical
Q1, Q2: BSS138; SOT-23
Q3, Q4, Q5, Q6: Q_PNP_BEC; TO-92
R1, R2, R3, R4, R9, R49, R50: 1.2k; R_0805_2012Metric
R5, R6, R7, R8, R10, R39, R40, R41, R42, R47, R48, R51: 560; R_0805_2012Metric
R11, R12, R13, R14: 10k; R_0805_2012Metric
R15, R16, R17, R18, R31, R32, R33, R34, R35, R36, R37, R38: 470; R_0805_2012Metric
R19, R20, R25, R26, R27, R28, R29, R30: 2.2k; R_0805_2012Metric
R21, R22, R23, R24, R43, R44, R45, R46: 1k; R_0805_2012Metric
SW1, SW2, SW3, SW4: SW_Push_SPDT; wuert_WS-SLTV
U1: MCP2515
U2: LM7810-10V; TO-220-3_Vertical
U3, U4: LTV-847; SOIC254P1016X460-16N

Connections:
+3.3V: A1.17 (3V3), C5.2, C7.2, C8.2, Q1.1 (G), Q2.1 (G), R11.1, R12.1
+5V: A1.27 (+5V), C6.1, C9.1, C10.1, C11.1, C12.1, J2.12, J3.12, R13.1, R14.1, U1.7 (+5V), U3.10, U3.12, U3.14, U3.16
+10V: A1.30 (VIN), C3.1, C4.2, C13.1, C14.1, C16.1, U2.3 (VO)
+12V: C1.2, C2.2, J6.12, J7.1, Q3.2 (E), Q4.2 (E), Q5.2 (E), Q6.2 (E), R35.1, R36.1, R37.1, R38.1, U2.1 (VI)
CAN_H: J6.9, U1.9 (CAN_H)
CAN_L: J6.10, U1.8 (CAN_H)
D0: J6.7, R9.1
D6: J6.6, R50.1
D7: J6.5, R49.1
GND: A1.4 (GND), A1.29 (GND), C1.1, C2.1, C3.2, C4.1, C5.1, C6.2, C7.1, C8.1, C9.2, C10.2, C11.2, C12.2, C13.2, C14.2, C16.2, D1.1 (K), D11.1 (K), D12.1 (K), D13.1 (K), D14.1 (K), D15.1 (K), D16.1 (K), J2.2, J3.2, J4.4, J5.4, J5.6, J6.11, J7.2, R5.2, R6.2, R7.2, R8.2, R10.2, R15.1, R16.1, R17.1, R18.1, R21.2, R28.2, R47.2, R48.2, U1.6 (GND), U2.2 (GND), U3.2, U3.4, U3.6, U3.8, U4.2, U4.4, U4.6, U4.8, U4.9, U4.11, U4.13, U4.15
I2C SCL: J1.1, Q2.2 (S), R12.2
I2C SDA: J1.2, Q1.2 (S), R11.2
LH12-li ausfahren: D3.1 (K), D8.1 (K), J4.2, R19.1
LH12-li einfahren: D4.1 (K), D7.1 (K), J4.1, R20.1
LH12-re ausfahren: D5.1 (K), D9.1 (K), J5.2, R25.1
LH12-re einfahren: D6.1 (K), D10.1 (K), J5.1, R26.1
LI_auf_LH12: D3.2 (A), R31.1
LI_auf_sig: A1.5 (D2), R43.2
LI_zu_LH12: D4.2 (A), R32.1
LI_zu_sig: A1.6 (D3), R44.2
unnamed: A1.19 (A0), R17.2, U3.11
unnamed: A1.20 (A1), R18.2, U3.9
unnamed: A1.21 (A2), R15.2, U3.15
unnamed: A1.22 (A3), R16.2, U3.13
unnamed: A1.23 (A4), Q1.3 (D), R13.2
unnamed: A1.24 (A5), Q2.3 (D), R14.2
unnamed: A1.9 (D6), R2.2, R6.1
unnamed: A1.10 (D7), R1.2, R5.1
unnamed: A1.11 (D8), R4.2, R8.1
unnamed: A1.12 (D9), R3.2, R7.1
unnamed: A1.13 (D10), SW3.2 (B)
unnamed: A1.14 (D11), SW2.2 (B)
unnamed: A1.15 (D12), SW4.2 (B)
unnamed: A1.16 (D13), SW1.2 (B)
unnamed: D1.2 (A), R51.2
unnamed: D11.2 (A), R19.2
unnamed: D12.2 (A), R20.2
unnamed: D13.2 (A), R25.2
unnamed: D14.2 (A), R26.2
unnamed: D15.2 (A), R27.1, R28.1
unnamed: D16.2 (A), R29.1, R30.1
unnamed: J4.5, R24.2, R29.2
unnamed: J4.6, R23.2, R30.2
unnamed: J5.5, R22.2, R27.2
unnamed: Q3.1 (B), R35.2, R39.1
unnamed: Q3.3 (C), R31.2
unnamed: Q4.1 (B), R36.2, R40.1
unnamed: Q4.3 (C), R32.2
unnamed: Q5.1 (B), R37.2, R41.1
unnamed: Q5.3 (C), R33.2
unnamed: Q6.1 (B), R38.2, R42.1
unnamed: Q6.3 (C), R34.2
unnamed: R21.1, U3.7
unnamed: R22.1, U3.5
unnamed: R23.1, U3.3
unnamed: R24.1, U3.1
unnamed: R39.2, U4.16
unnamed: R40.2, U4.14
unnamed: R41.2, U4.12
unnamed: R42.2, U4.10
unnamed: R43.1, U4.1
unnamed: R44.1, U4.3
unnamed: R45.1, U4.5
unnamed: R46.1, U4.7
unnamed: SW1.1 (A), U1.2 (sck)
unnamed: R51.1, SW1.3 (C)
unnamed: SW2.1 (A), U1.3 (MOSI)
unnamed: R47.1, R50.2, SW2.3 (C)
unnamed: SW3.1 (A), U1.5 (CS)
unnamed: R48.1, R49.2, SW3.3 (C)
unnamed: SW4.1 (A), U1.4 (MISO)
unnamed: R9.2, R10.1, SW4.3 (C)
RE_auf_LH12: D5.2 (A), R33.1
RE_auf_sig: A1.7 (D4), R45.2
RE_zu_LH12: D6.2 (A), R34.1
RE_zu_sig: A1.8 (D5), R46.2
li-Position poti H: A1.26 (A7), J4.3
li-manuell-oeffnen: D8.2 (A), J6.2, R3.1
li-manuell-schliessen: D7.2 (A), J6.1, R4.1
re-Position poti H: A1.25 (A6), J5.3
re-manuell-oeffnen: D10.2 (A), J6.4, R1.1
re-manuell-schliessen: D9.2 (A), J6.3, R2.1

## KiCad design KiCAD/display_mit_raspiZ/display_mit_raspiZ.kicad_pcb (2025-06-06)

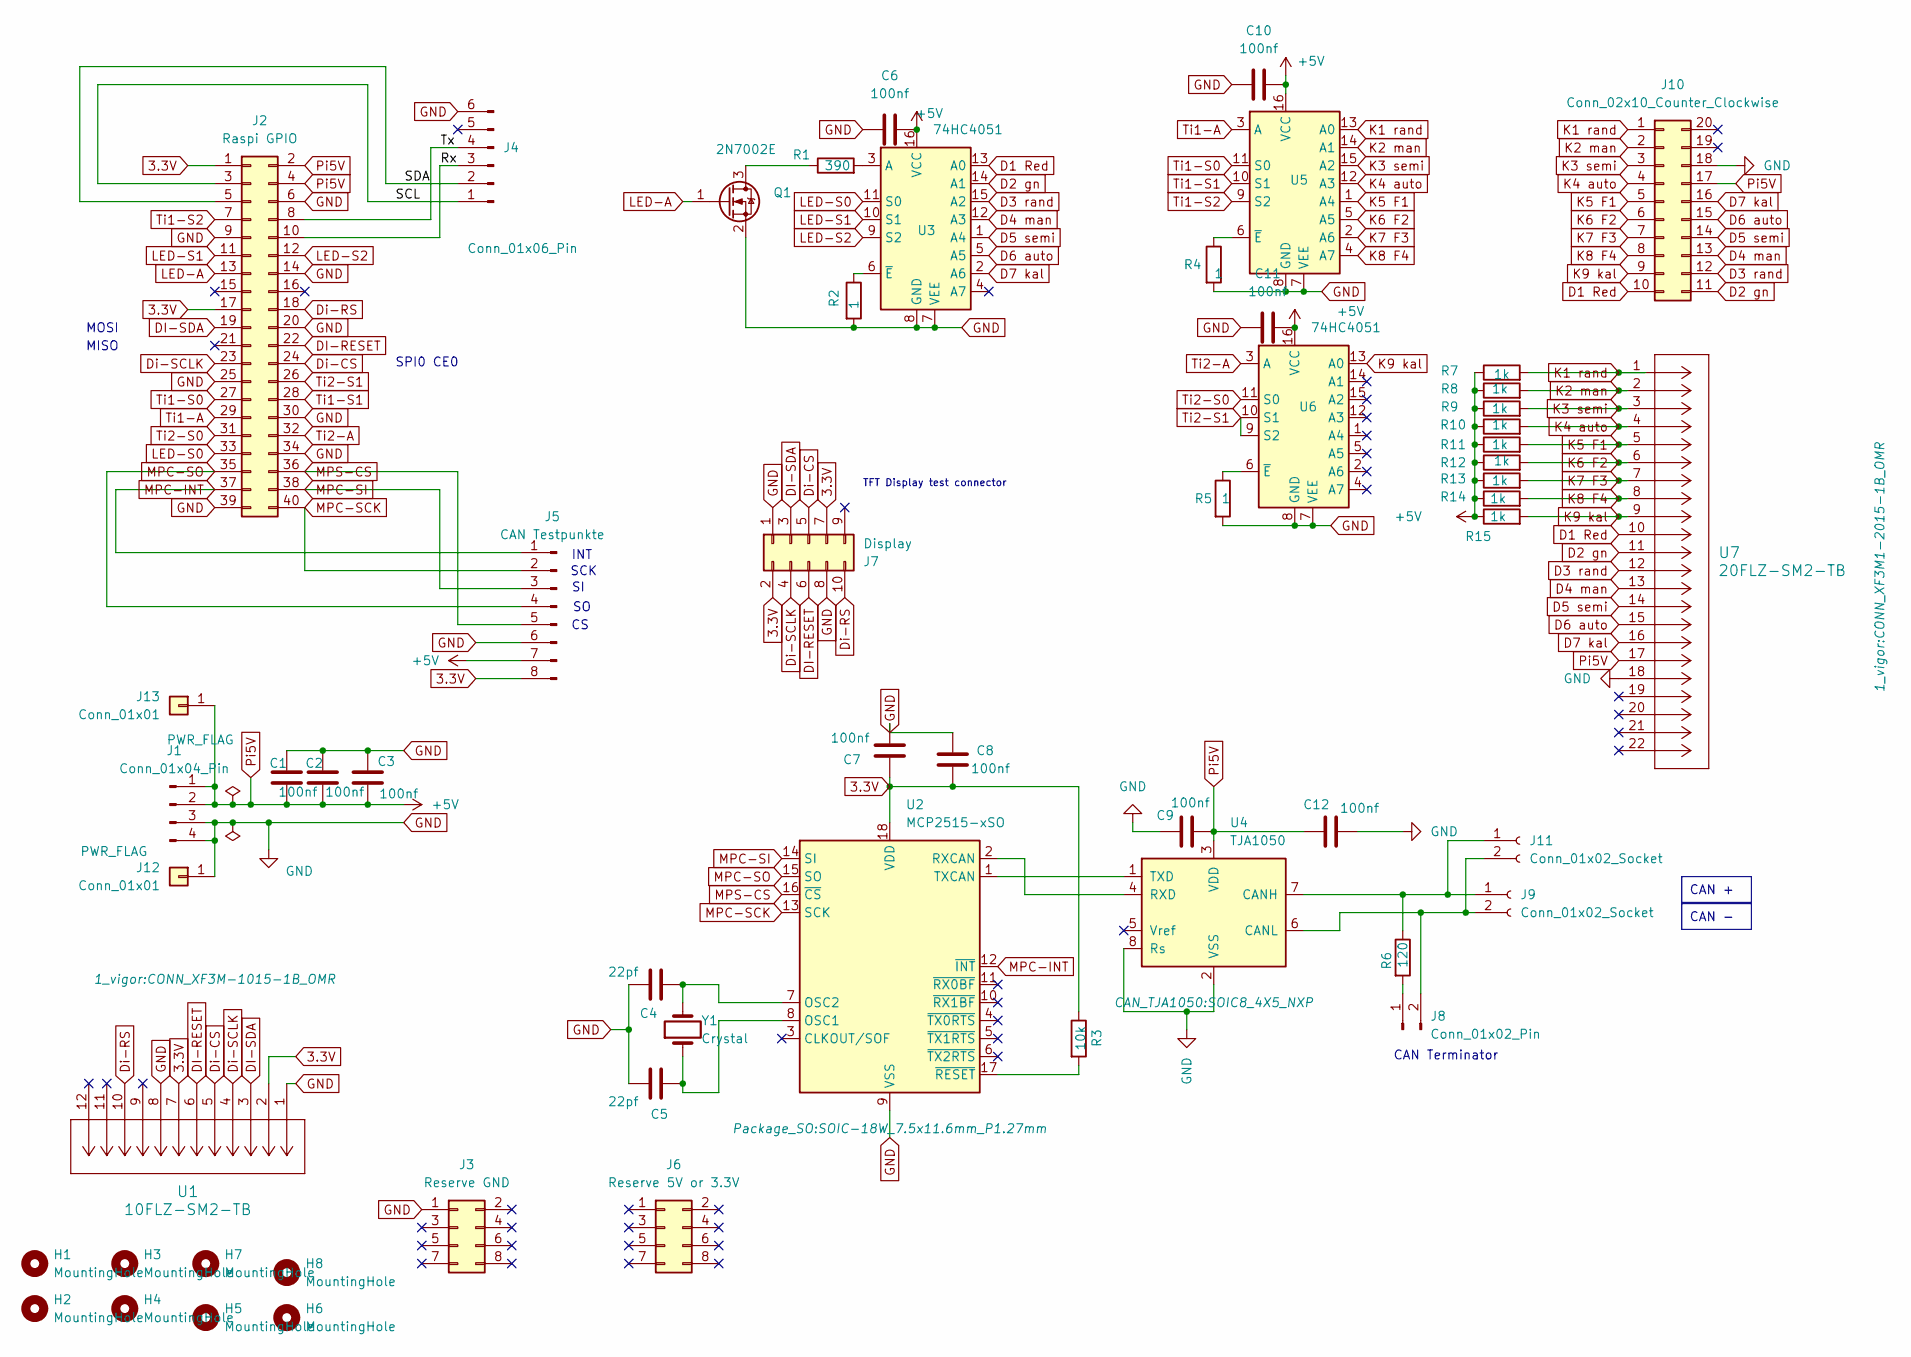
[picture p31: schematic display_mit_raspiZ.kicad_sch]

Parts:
C1, C2, C3, C6, C7, C8, C9, C10, C11, C12: 100nf; C_0805_2012Metric
C4, C5: 22pf; CAPC17595_87N_KEM
H1, H2, H3, H4, H5, H6, H7, H8: MountingHole; MountingHole_3.2mm_M3_ISO7380_Pad
J1: Conn_01x04_Pin; PinHeader_1x04_P2.54mm_Vertical
J2: Raspi GPIO; PinHeader_2x20_P2.54mm_Vertical
J3: Reserve GND; PinHeader_2x05_P2.54mm_Vertical
J4: Conn_01x06_Pin; PinHeader_1x06_P2.54mm_Vertical
J5: CAN Testpunkte; PinHeader_1x08_P2.54mm_Vertical
J6: Reserve 5V or 3.3V; PinHeader_2x05_P2.54mm_Vertical
J7: Display; PinHeader_2x05_P2.54mm_Vertical
J8: Conn_01x02_Pin; PinHeader_1x02_P2.54mm_Vertical
J9, J11: Conn_01x02_Socket; PinHeader_1x02_P2.54mm_Vertical
J10: Conn_02x10_Counter_Clockwise; PinHeader_2x10_P2.54mm_Vertical
J12, J13: Conn_01x01; Flachst_2.5mm
Q1: 2N7002E; SOT-23
R1: 390; R_1206_3216Metric
R2, R4, R5: 1; R_0805_2012Metric
R3: 10k; R_0805_2012Metric
R6: 120; R_1206_3216Metric
R7, R8, R9, R10, R11, R12, R13, R14, R15: 1k; R_0805_2012Metric
U1: 10FLZ-SM2-TB; CONN_XF3M-1015-1B_OMR
U2: MCP2515-xSO; SOIC-18W_7.5x11.6mm_P1.27mm
U3, U5, U6: 74HC4051; SOIC-16_3.9x9.9mm_P1.27mm
U4: TJA1050; SOIC8_4X5_NXP
U7: 20FLZ-SM2-TB; CONN_XF3M1-2015-1B_OMR
Y1: Crystal; Crystal_SMD_Abracon_ABM3-2Pin_5.0x3.2mm_HandSoldering

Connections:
3.3V: C7.2, C8.2, J2.1, J2.17, J5.8, J7.2, J7.7, R3.1, U1.2, U1.7, U2.18 (VDD)
/Rx: J2.10, J4.3
/SCL: J2.3, J4.1
/SDA: J2.5, J4.2
/Tx: J2.8, J4.4
D1 Red: J10.10, U3.13 (A0), U7.10
D2 gn: J10.11, U3.14 (A1), U7.11
D3 rand: J10.12, U3.15 (A2), U7.12
D4 man: J10.13, U3.12 (A3), U7.13
D5 semi: J10.14, U3.1 (A4), U7.14
D6 auto: J10.15, U3.5 (A5), U7.15
D7 kal: J10.16, U3.2 (A6), U7.16
DI-RESET: J2.22, J7.6, U1.6
DI-SDA: J2.19, J7.3, U1.3
Di-CS: J2.24, J7.5, U1.5
Di-RS: J2.18, J7.10, U1.10
Di-SCLK: J2.23, J7.4, U1.4
GND: C1.1, C2.1, C3.1, C4.1, C5.1, C6.1, C7.1, C8.1, C9.1, C10.1, C11.1, C12.2, J1.3, J1.4, J2.6, J2.9, J2.14, J2.20, J2.25, J2.30, J2.34, J2.39, J3.1, J4.6, J5.6, J7.1, J7.8, J10.18, J12.1, Q1.2 (S), R2.2, R4.2, R5.2, U1.1, U1.8, U2.9 (VSS), U3.7 (VEE), U3.8 (GND), U4.2 (VSS), U4.8 (Rs), U5.7 (VEE), U5.8 (GND), U6.7 (VEE), U6.8 (GND), U7.18
K1 rand: J10.1, R7.2, U5.13 (A0), U7.1
K2 man: J10.2, R8.2, U5.14 (A1), U7.2
K3 semi: J10.3, R9.2, U5.15 (A2), U7.3
K4 auto: J10.4, R10.2, U5.12 (A3), U7.4
K5 F1: J10.5, R11.2, U5.1 (A4), U7.5
K6 F2: J10.6, R12.2, U5.5 (A5), U7.6
K7 F3: J10.7, R13.2, U5.2 (A6), U7.7
K8 F4: J10.8, R14.2, U5.4 (A7), U7.8
K9 kal: J10.9, R15.2, U6.13 (A0), U7.9
LED-A: J2.13, Q1.1 (G)
LED-S0: J2.33, U3.11 (S0)
LED-S1: J2.11, U3.10 (S1)
LED-S2: J2.12, U3.9 (S2)
MPC-INT: J2.37, J5.1, U2.12 (~INT)
MPC-SCK: J2.40, J5.2, U2.13 (SCK)
MPC-SI: J2.38, J5.3, U2.14 (SI)
MPC-SO: J2.35, J5.4, U2.15 (SO)
MPS-CS: J2.36, J5.5, U2.16 (~CS)
unnamed: J8.1, R6.2
unnamed: J9.1, J11.1, R6.1, U4.7 (CANH)
unnamed: J8.2, J9.2, J11.2, U4.6 (CANL)
unnamed: Q1.3 (D), R1.1
unnamed: C5.2, U2.8 (OSC1), Y1.1
unnamed: C4.2, U2.7 (OSC2), Y1.2
unnamed: U2.2 (RXCAN), U4.4 (RXD)
unnamed: U2.1 (TXCAN), U4.1 (TXD)
unnamed: R3.2, U2.17 (~RESET)
unnamed: R1.2, U3.3 (A)
unnamed: R2.1, U3.6 (~E)
unnamed: R4.1, U5.6 (~E)
unnamed: R5.1, U6.6 (~E)
Pi5V: C1.2, C2.2, C3.2, C6.2, C9.2, C10.2, C11.2, C12.1, J1.1, J1.2, J2.2, J2.4, J5.7, J10.17, J13.1, R7.1, R8.1, R9.1, R10.1, R11.1, R12.1, R13.1, R14.1, R15.1, U3.16 (VCC), U4.3 (VDD), U5.16 (VCC), U6.16 (VCC), U7.17
Ti1-A: J2.29, U5.3 (A)
Ti1-S0: J2.27, U5.11 (S0)
Ti1-S1: J2.28, U5.10 (S1)
Ti1-S2: J2.7, U5.9 (S2)
Ti2-A: J2.32, U6.3 (A)
Ti2-S0: J2.31, U6.11 (S0)
Ti2-S1: J2.26, U6.9 (S2), U6.10 (S1)

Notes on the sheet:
CAN +
CAN -
SCK
CAN Terminator
MISO
SPI0 CE0
INT
MOSI
TFT Display test connector

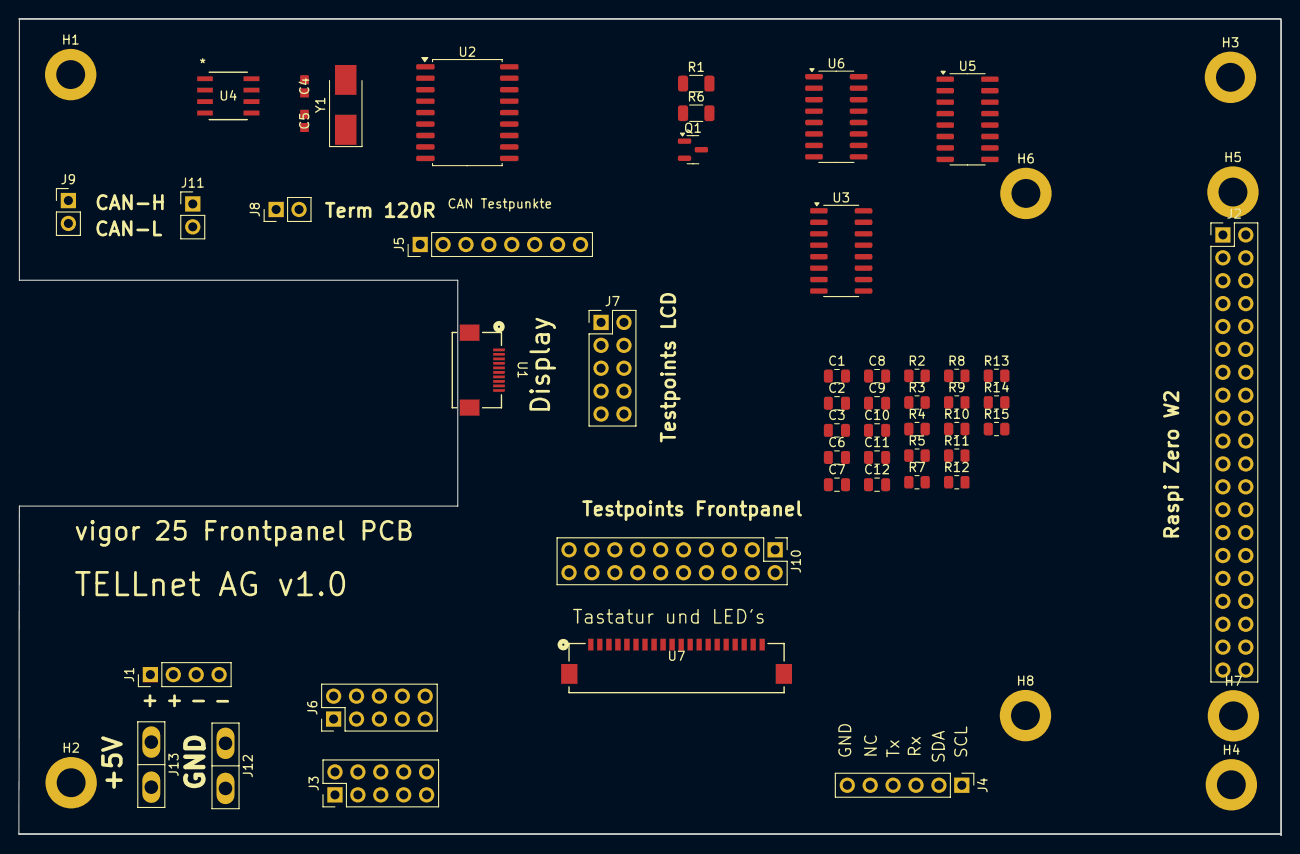
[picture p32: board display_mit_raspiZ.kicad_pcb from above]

Board: 2 copper layers, 140.0 x 90.5 mm, 57 parts (0 on the bottom side), 57 nets.

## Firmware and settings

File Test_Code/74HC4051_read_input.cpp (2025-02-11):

// Pins für die Steuerung des 74HC4051
const int S0 = 2;
const int S1 = 3;
const int S2 = 4;

// Pin für das Lesen des Signals
const int Z = 5;

void setup() {
 // Setze die Steuerpins als Ausgänge
 pinMode(S0, OUTPUT);
 pinMode(S1, OUTPUT);
 pinMode(S2, OUTPUT);

 // Setze den Z-Pin als Eingang
 pinMode(Z, INPUT);

 // Starte die serielle Kommunikation
 Serial.begin(9600);
}

void loop() {
 // Durchlaufe alle 8 Kanäle
 for (int channel = 0; channel < 8; channel++) {
   // Setze die Steuerpins entsprechend dem aktuellen Kanal
   digitalWrite(S0, bitRead(channel, 0));
   digitalWrite(S1, bitRead(channel, 1));
   digitalWrite(S2, bitRead(channel, 2));

   // Lese den Wert vom Z-Pin
   int value = digitalRead(Z);

   // Gib den Kanal und den gelesenen Wert aus
   Serial.print("Kanal ");
   Serial.print(channel);
   Serial.print(": ");
   Serial.println(value);

   // Kurze Verzögerung für die Stabilität
   delay(100);
 }

 // Warte eine Sekunde, bevor der nächste Durchlauf beginnt
 delay(1000);
}

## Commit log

2024-10-23 Raspi SPI Interface
2025-02-11 Initial draft. Da muss noch Struktir rein
    [Vigor_Kommunikationmatrix.xlsx]
2025-02-13 diverse update und Ergänzungen
2025-02-13 div kleine updates
    [Vigor_Kommunikation_subsysteme.xlsx]
2025-02-13 Create motor_regler.pdf
    zugefügt Schema Regler
2025-03-12 Create display_lib_install_auf_neuem_Raspi.txt
    beschreibt die Installation auf einem neuen Raspi bei dem nur die lite version installiert ist
2025-06-03 Skizze Randstreuen, Korrekturen PCB pendent
2025-06-06 KiCAD Files published
    [CAN_.kicad_sch, display_mit_raspiZ.kicad_pcb, display_mit_raspiZ.kicad_sch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]
2025-06-06 Schema entfernt, Aktuelle Schema ist nun unter KiCAD
2025-06-23 Print in Controllerbox hinzugefügt
    Entkopplungskondensator bei MCP2515 Reset hinzugefügt
    MCP2515 Speisung auf 5V angepasst
    Kosmetik
    [H-bridge.kicad_sch, LTV-847S.step, display_mit_raspiZ.kicad_sch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]
2025-06-23 Ti2-S1 und -S2 am Raspi GPIO geändert
    [display_mit_raspiZ.kicad_sch]
2025-06-30 updated calib display
    changed "abdrehen" to "auf" und "zu"
